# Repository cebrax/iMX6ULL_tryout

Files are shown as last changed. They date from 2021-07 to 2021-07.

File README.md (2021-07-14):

# iMX6ULL_tryout

This is a test board to get iMX6ULL up and running using KiCad 5.99

The board has:

- iMX6ULL 900MHz MCIMX6Y2DVM09AB
- 512MB DDR3L RAM
- An SD card slot
- 2 x USB connector
- An ethernet PHY and connector with magnetics
- A 40-pin LCD connector
- Various pinouts of GPIO, RS232 and such..

Front
Back


StressTest

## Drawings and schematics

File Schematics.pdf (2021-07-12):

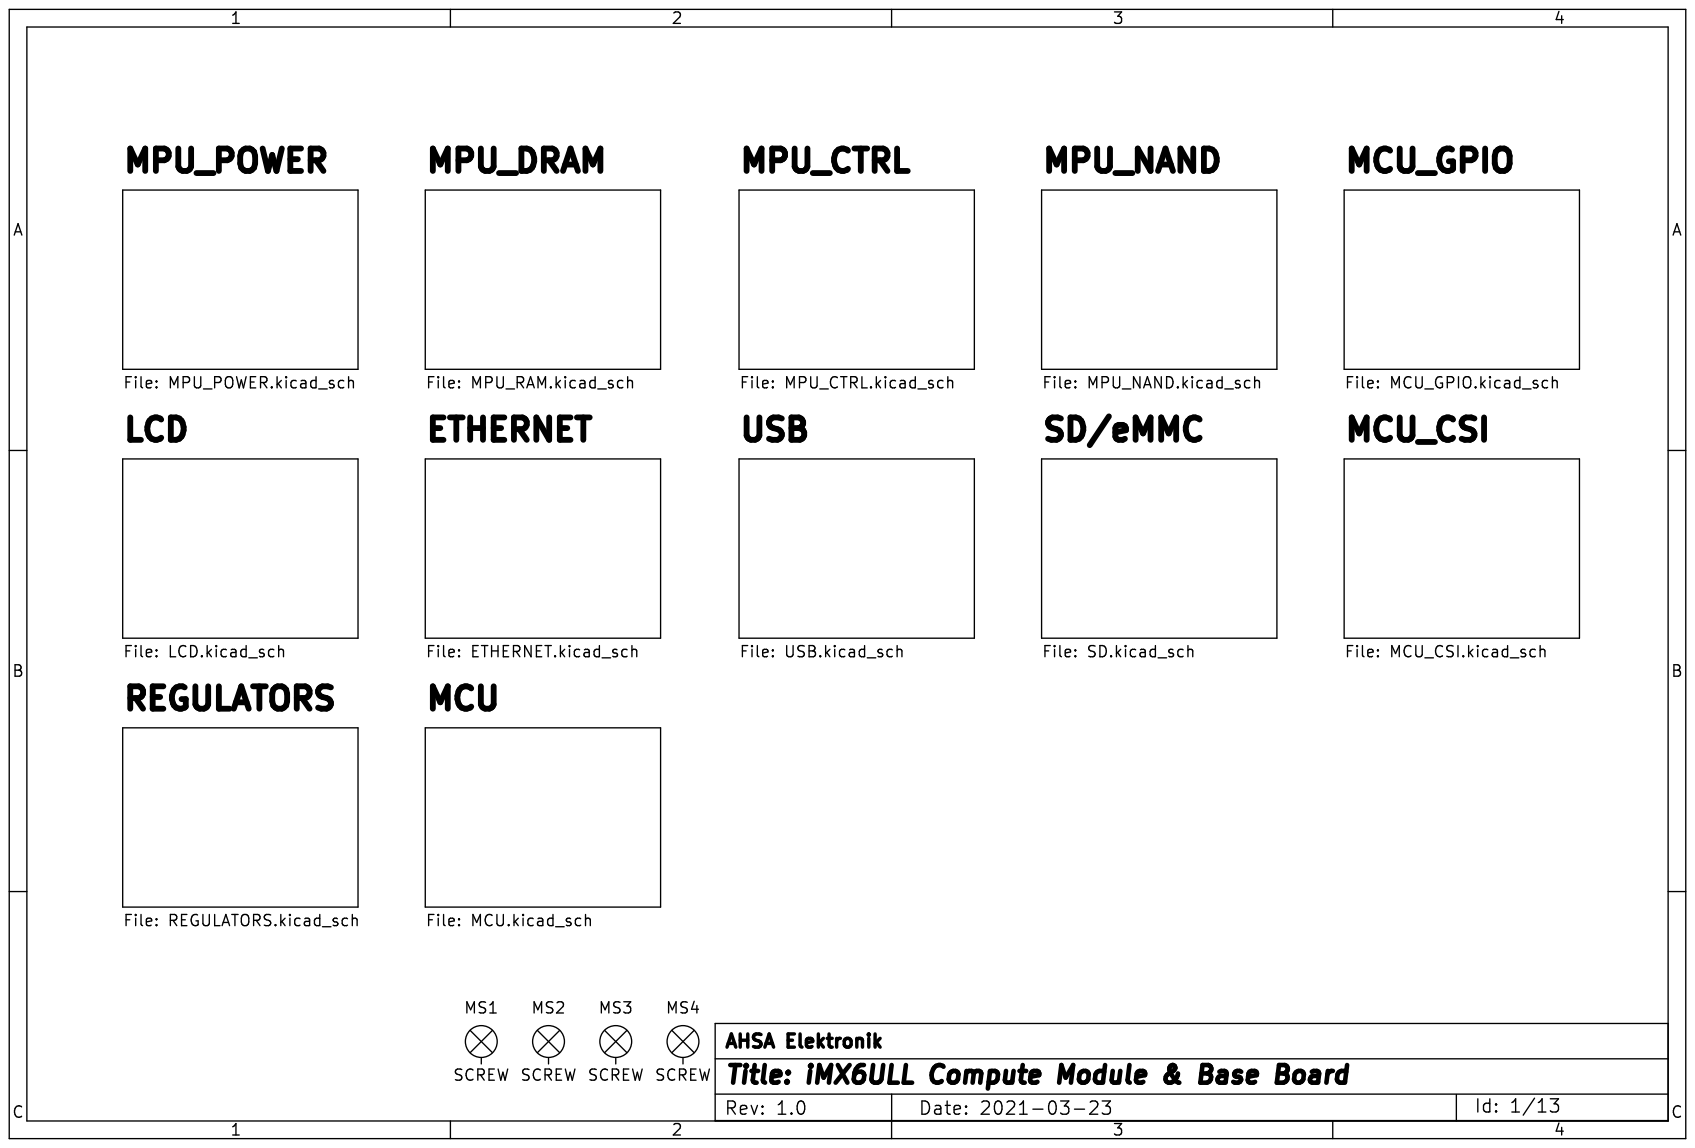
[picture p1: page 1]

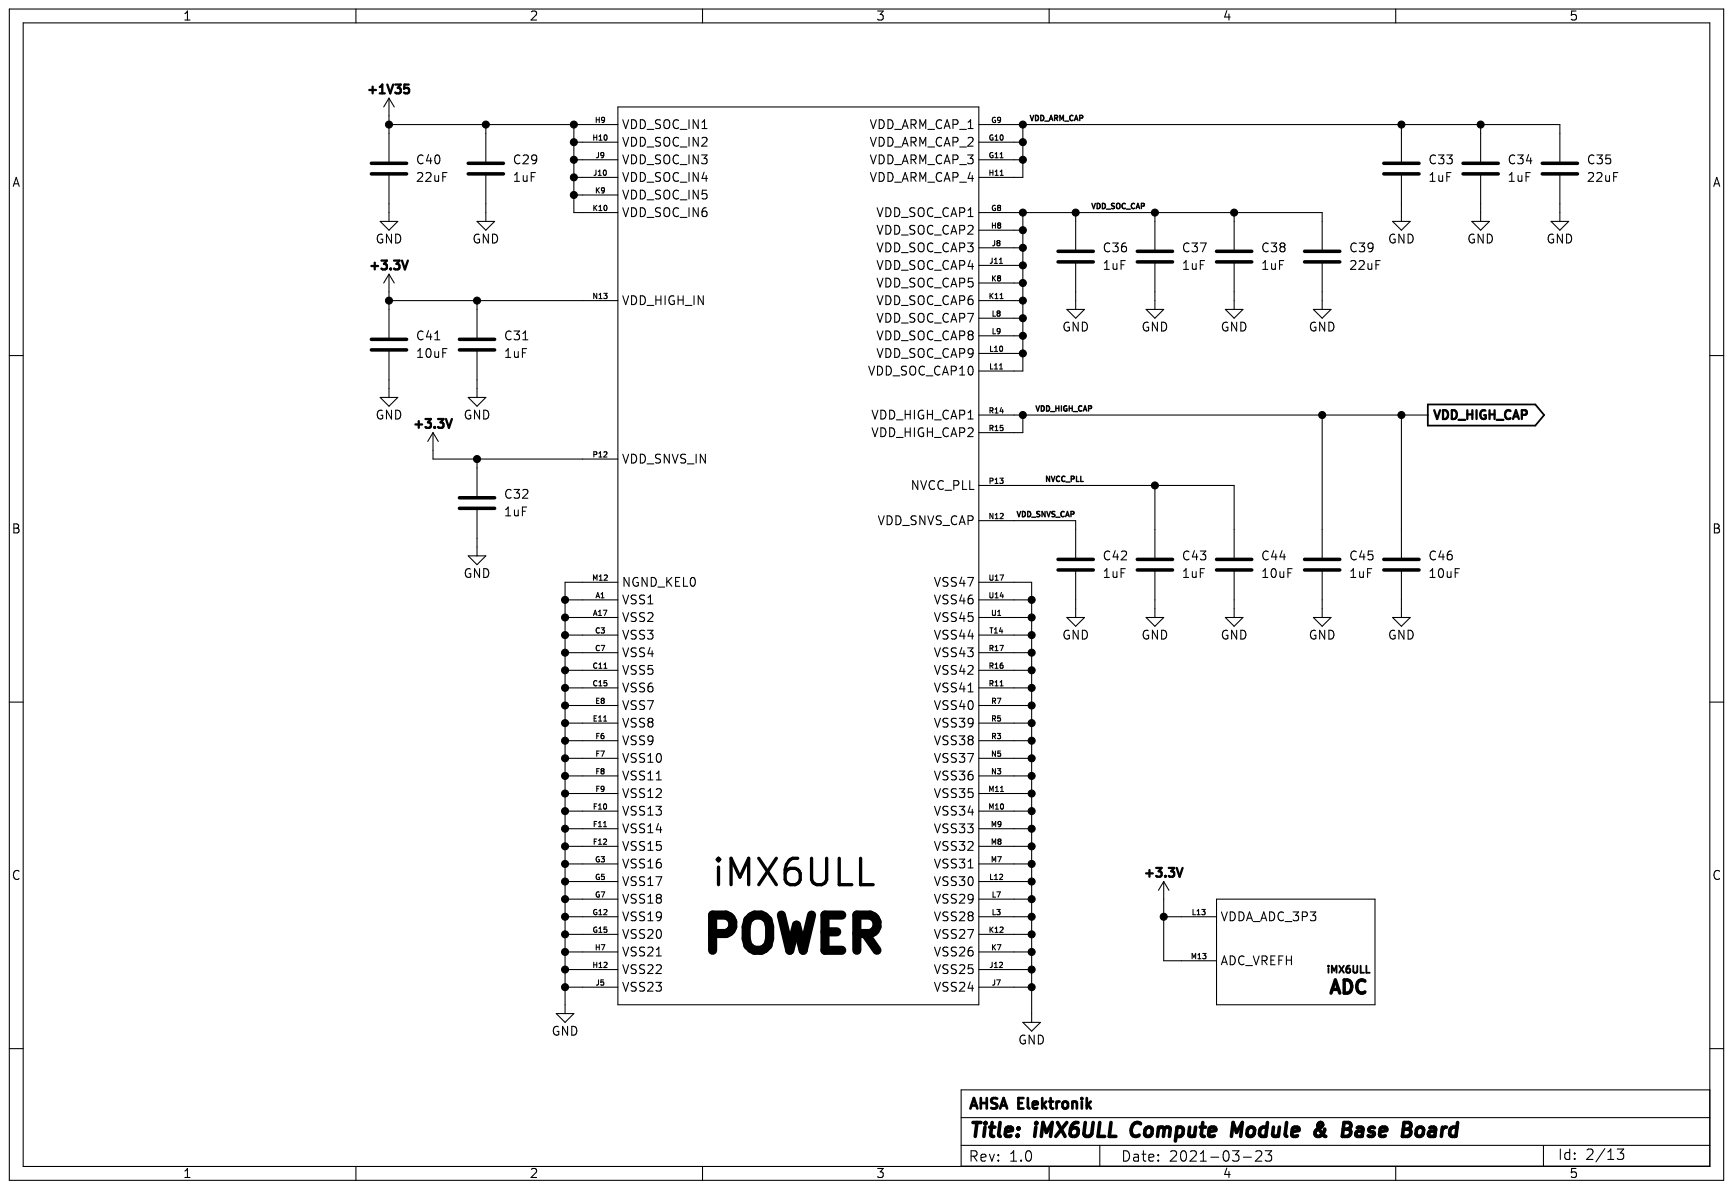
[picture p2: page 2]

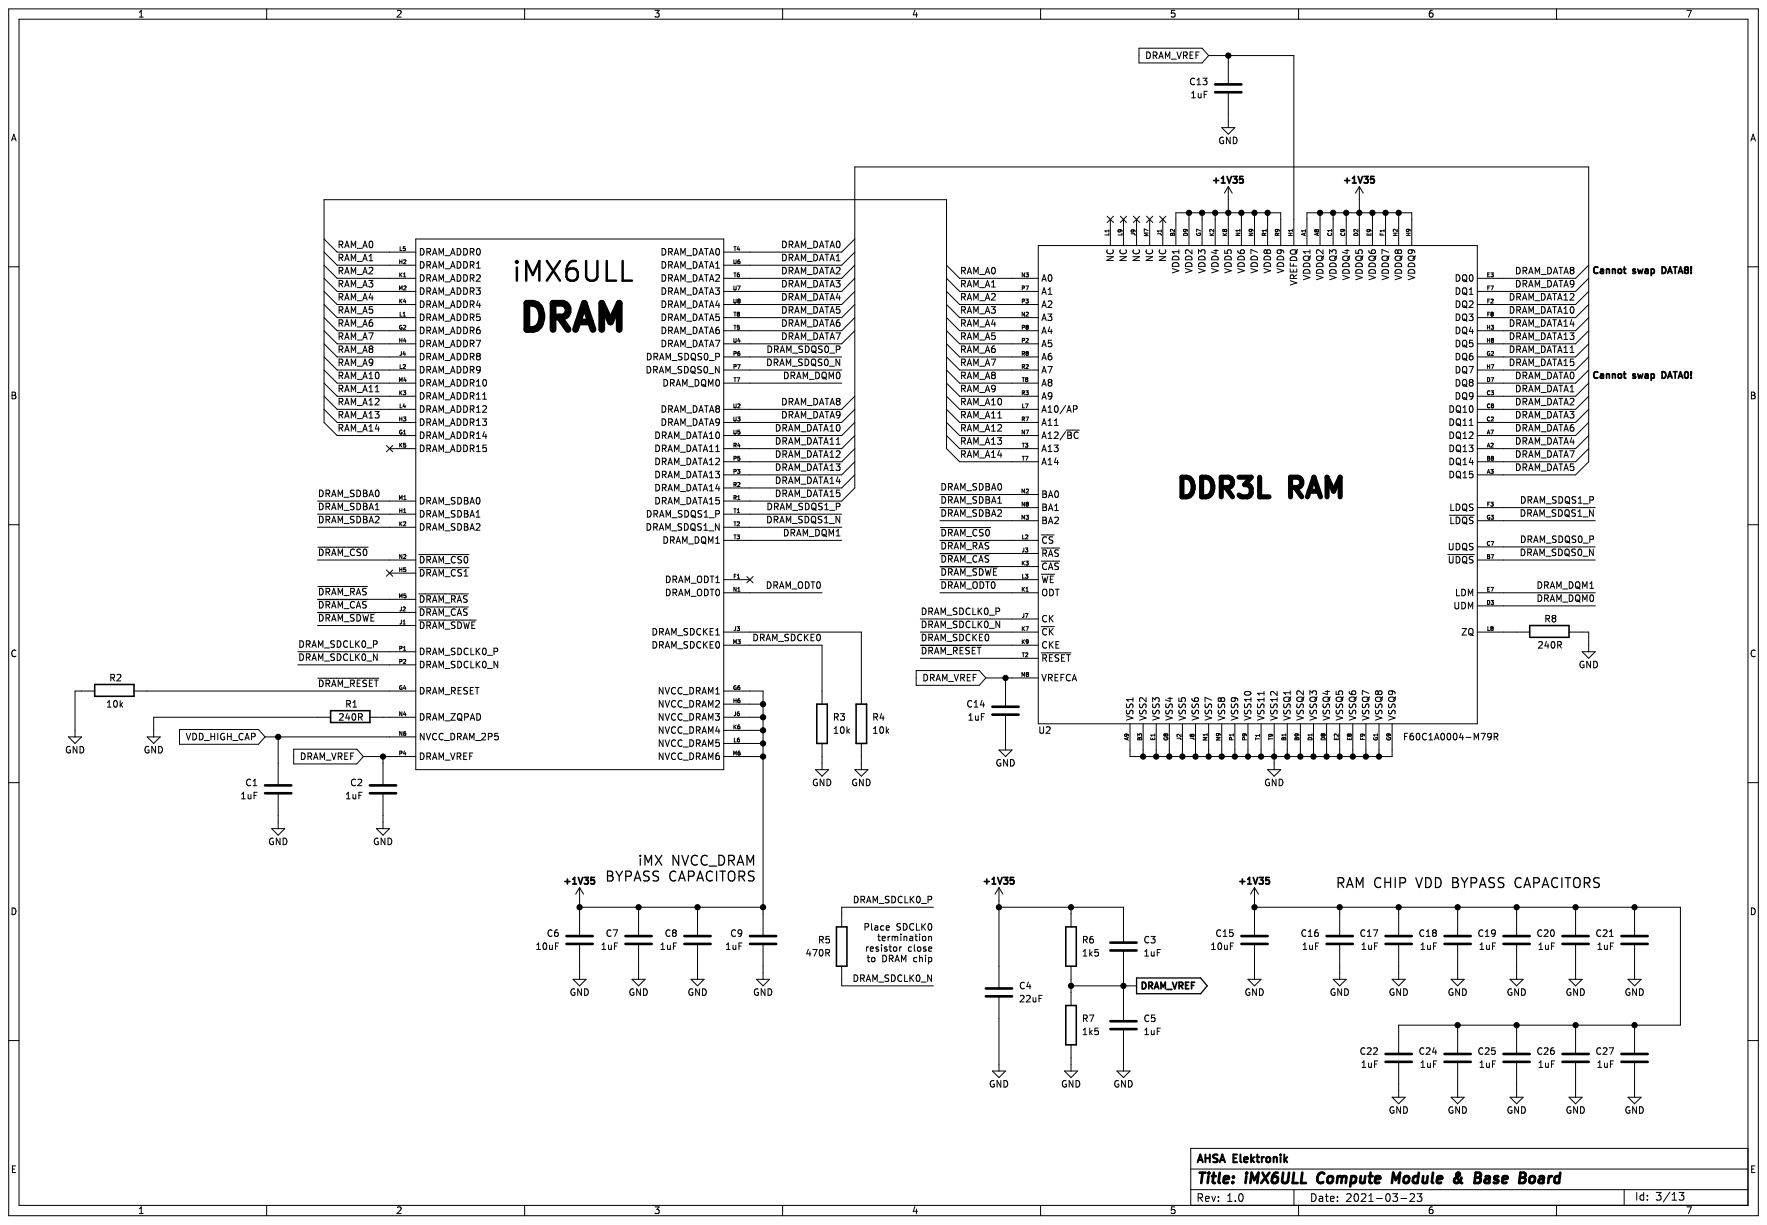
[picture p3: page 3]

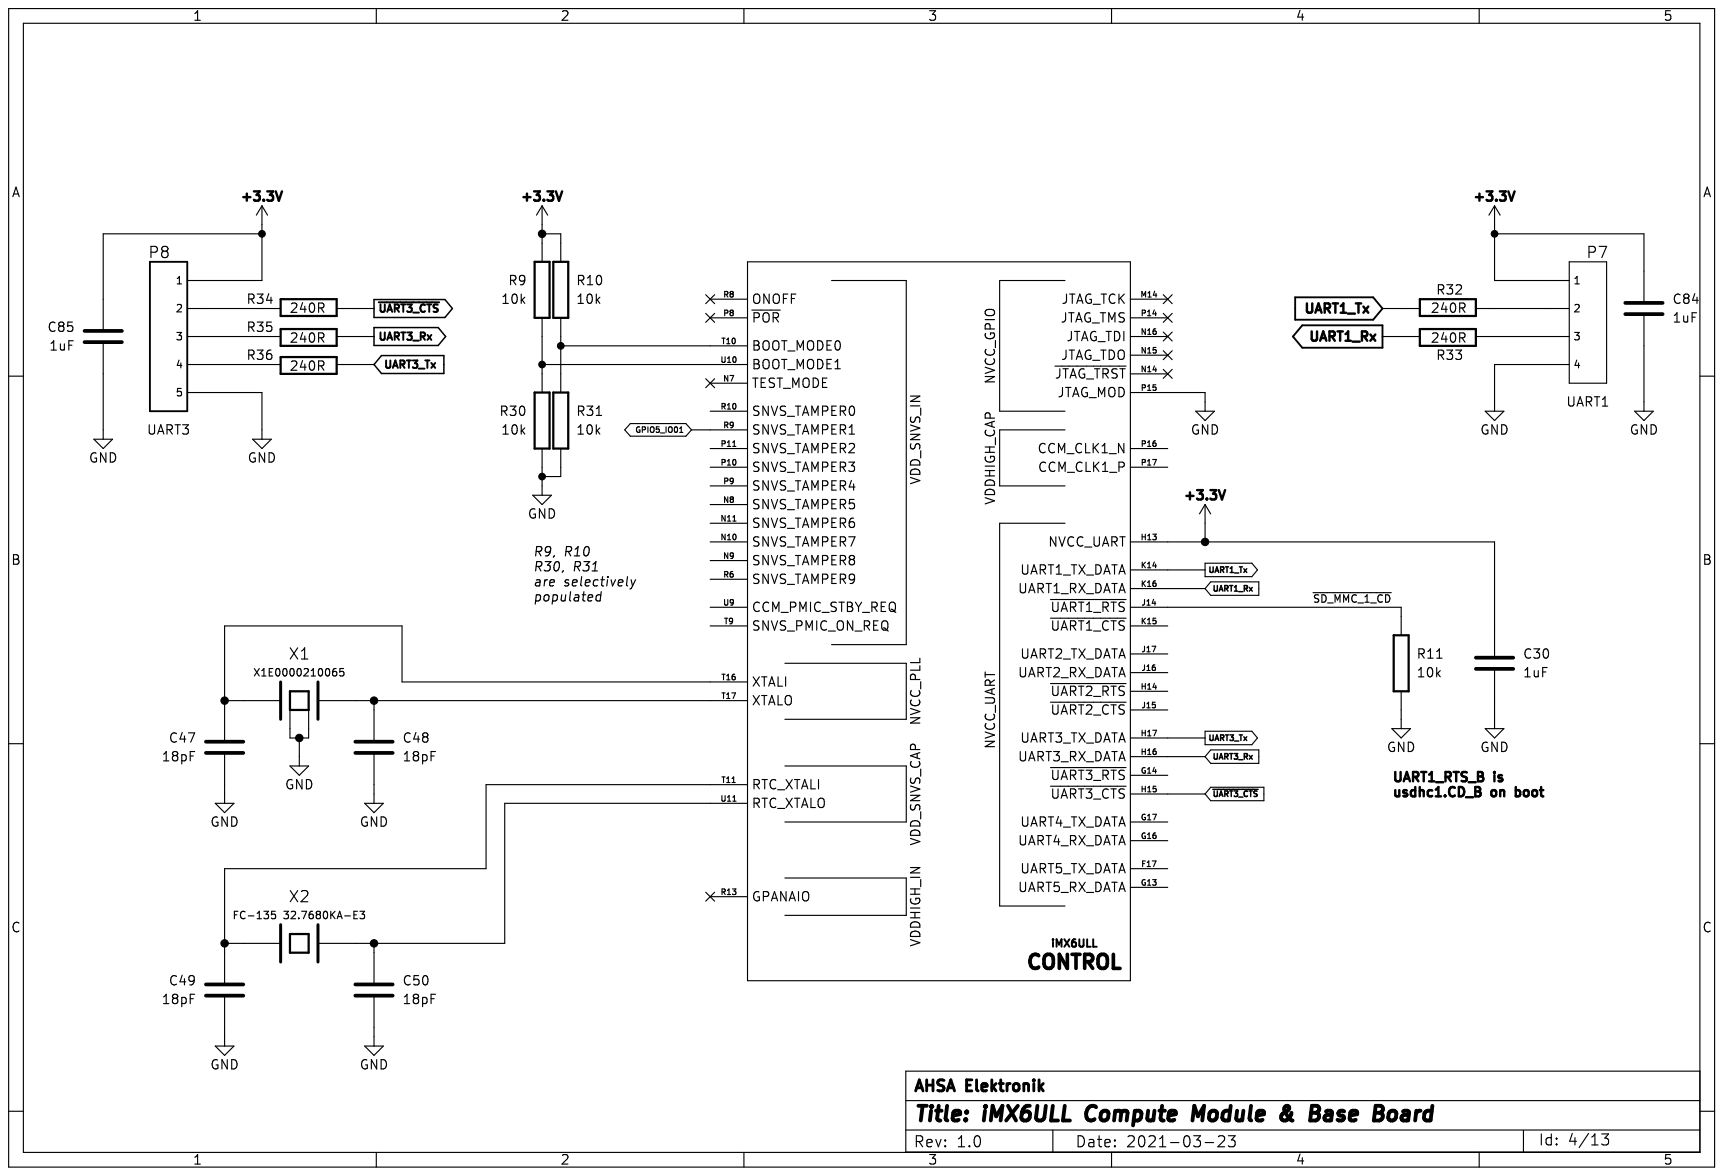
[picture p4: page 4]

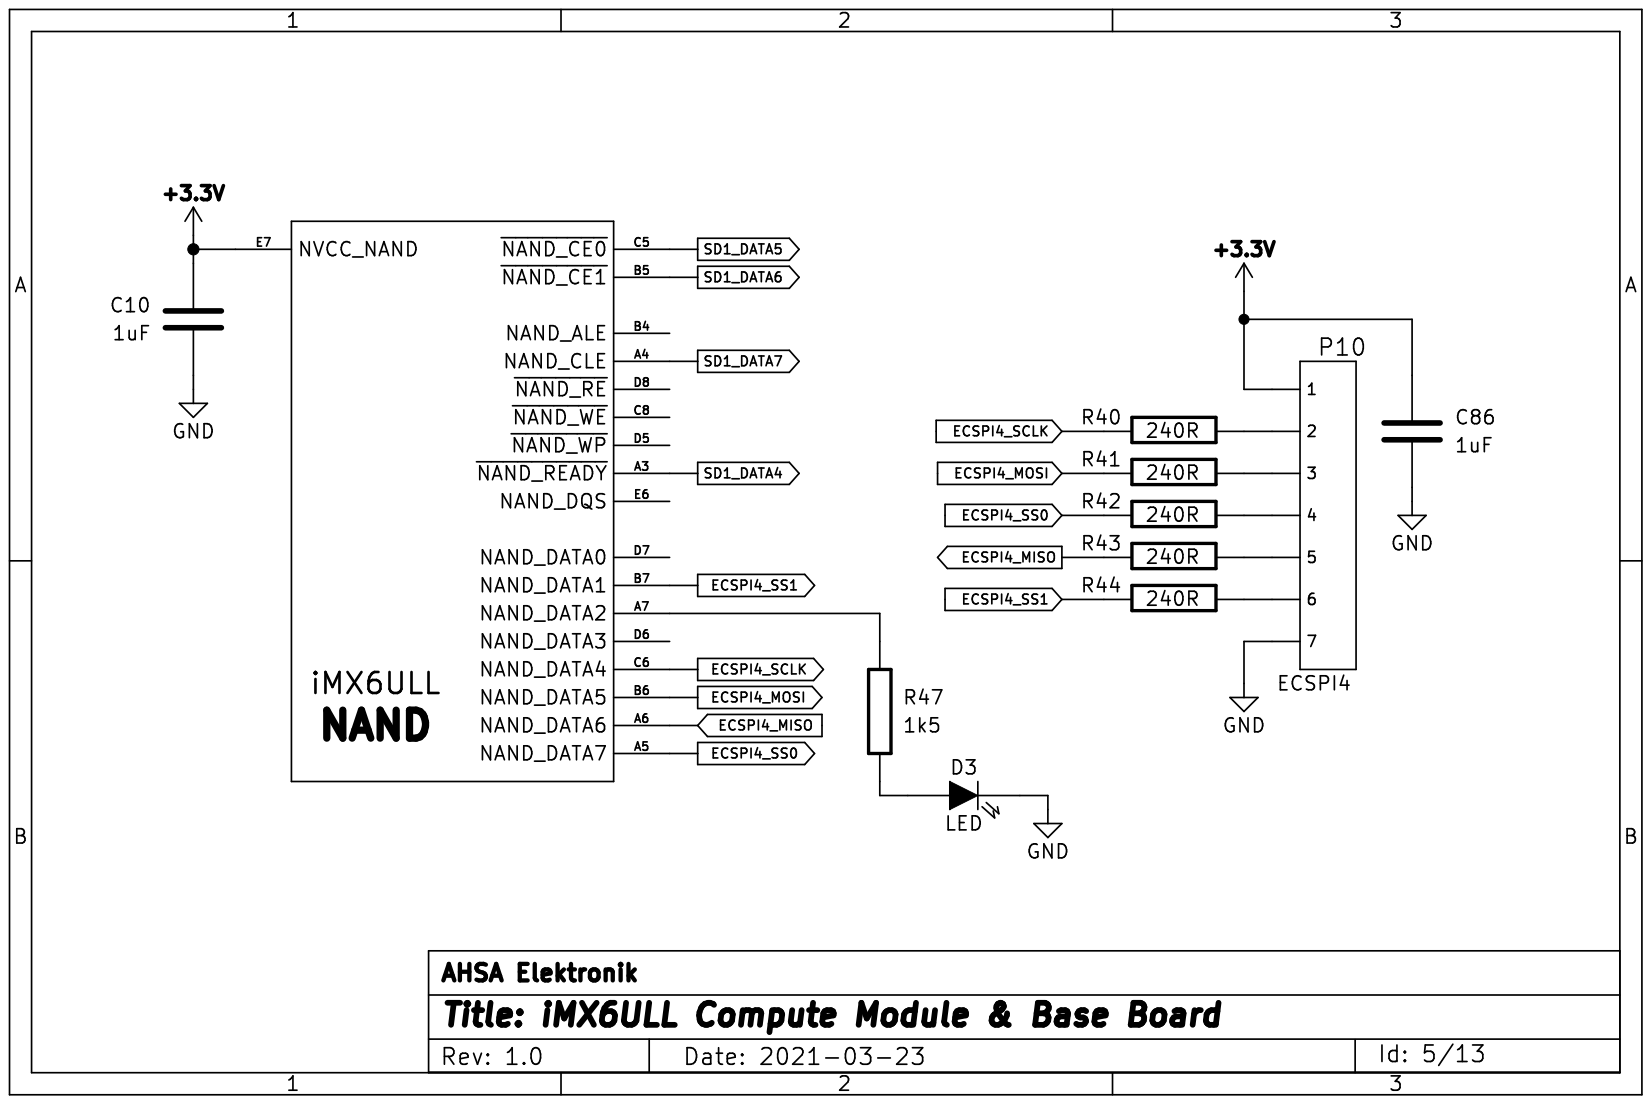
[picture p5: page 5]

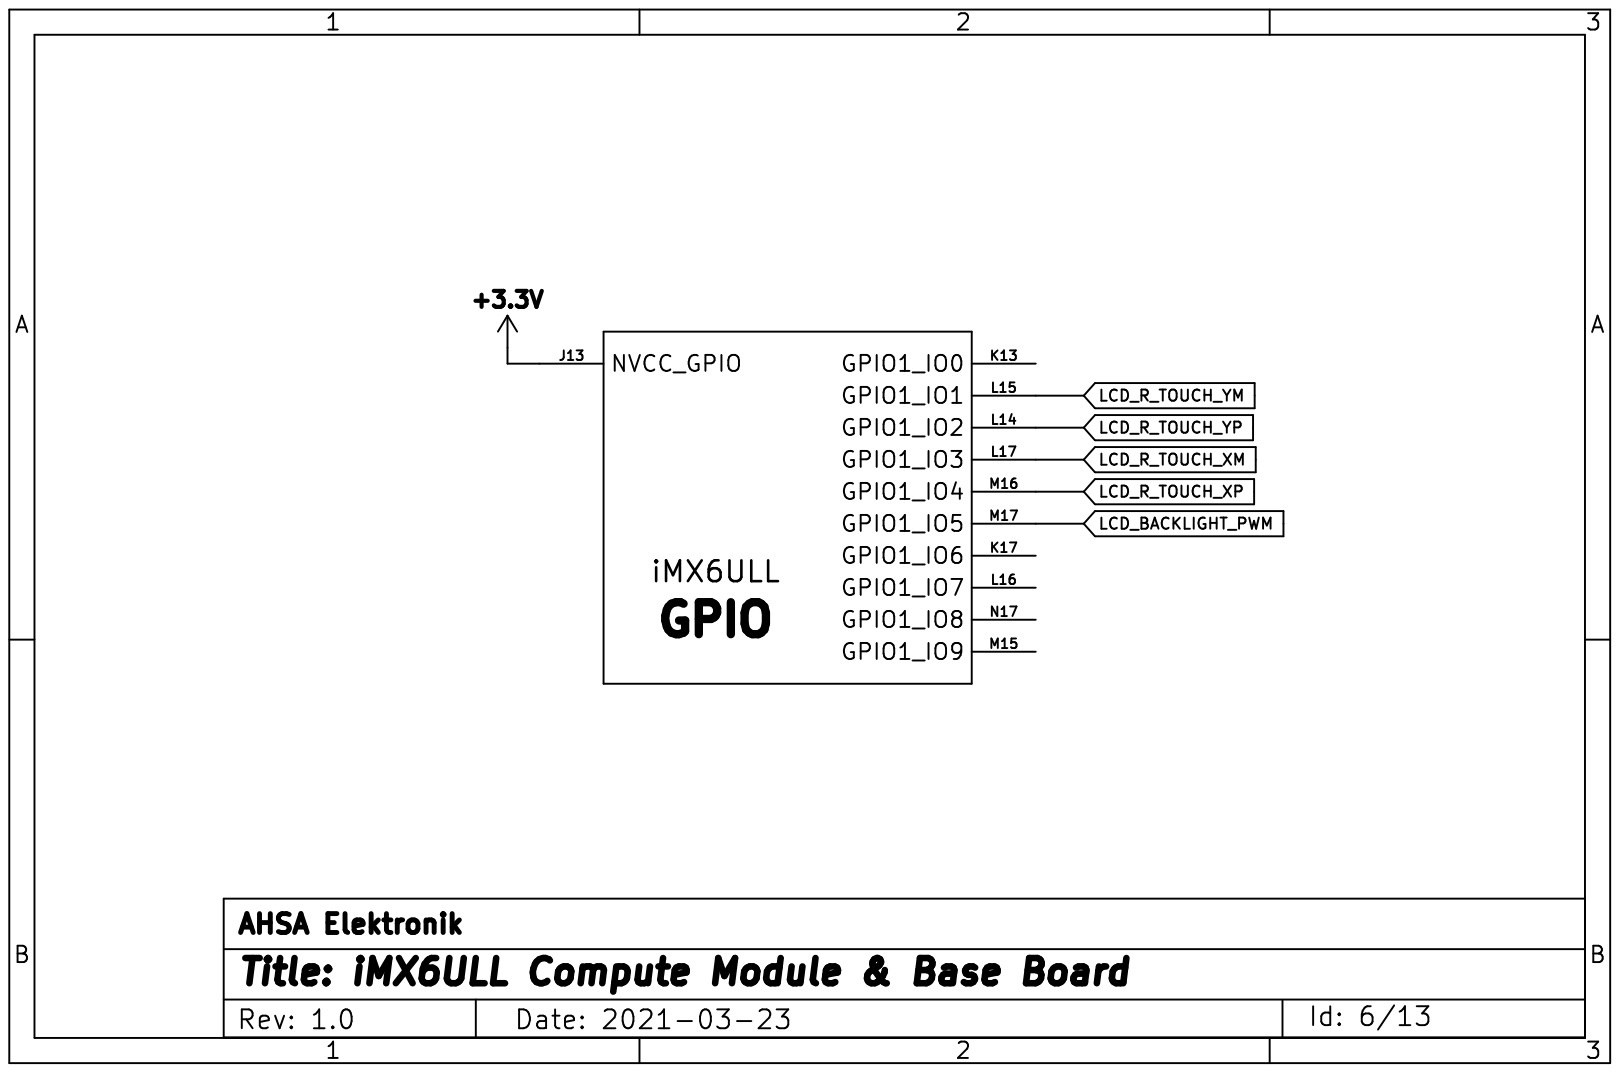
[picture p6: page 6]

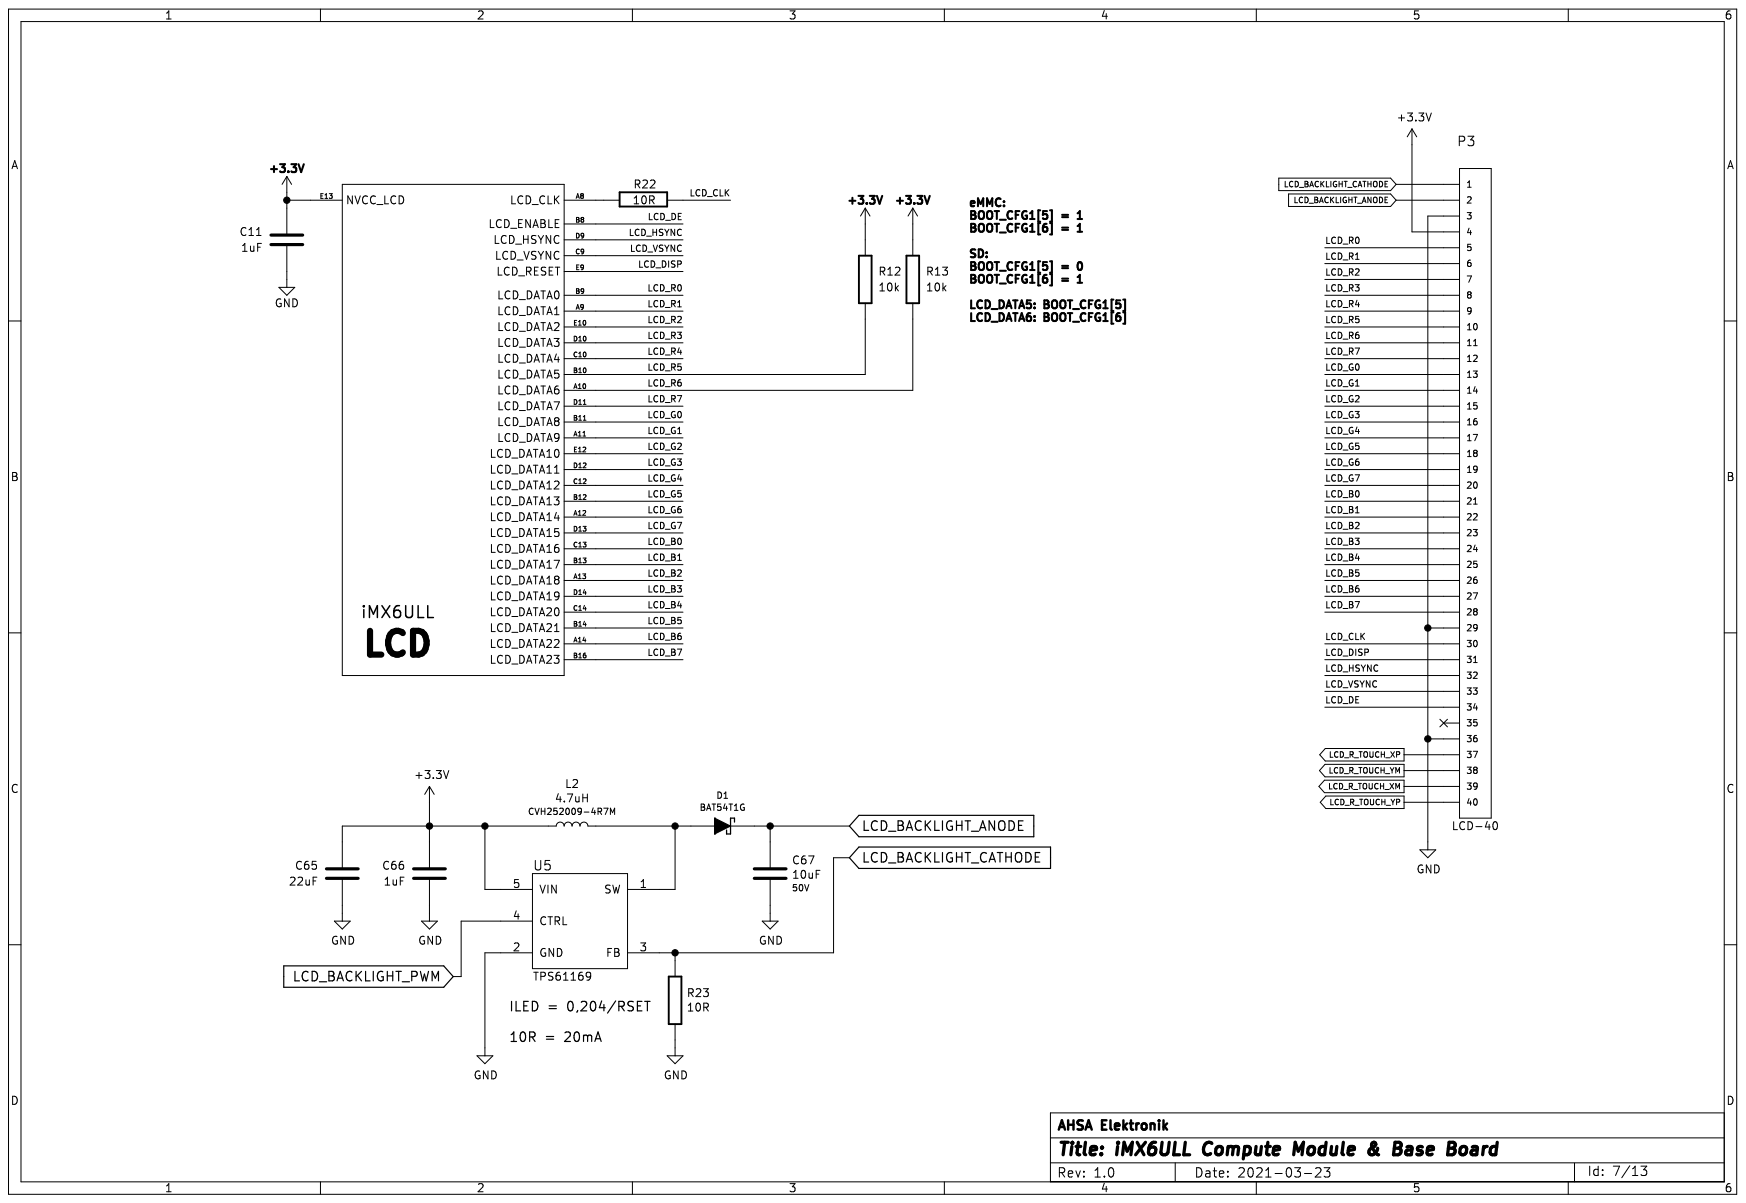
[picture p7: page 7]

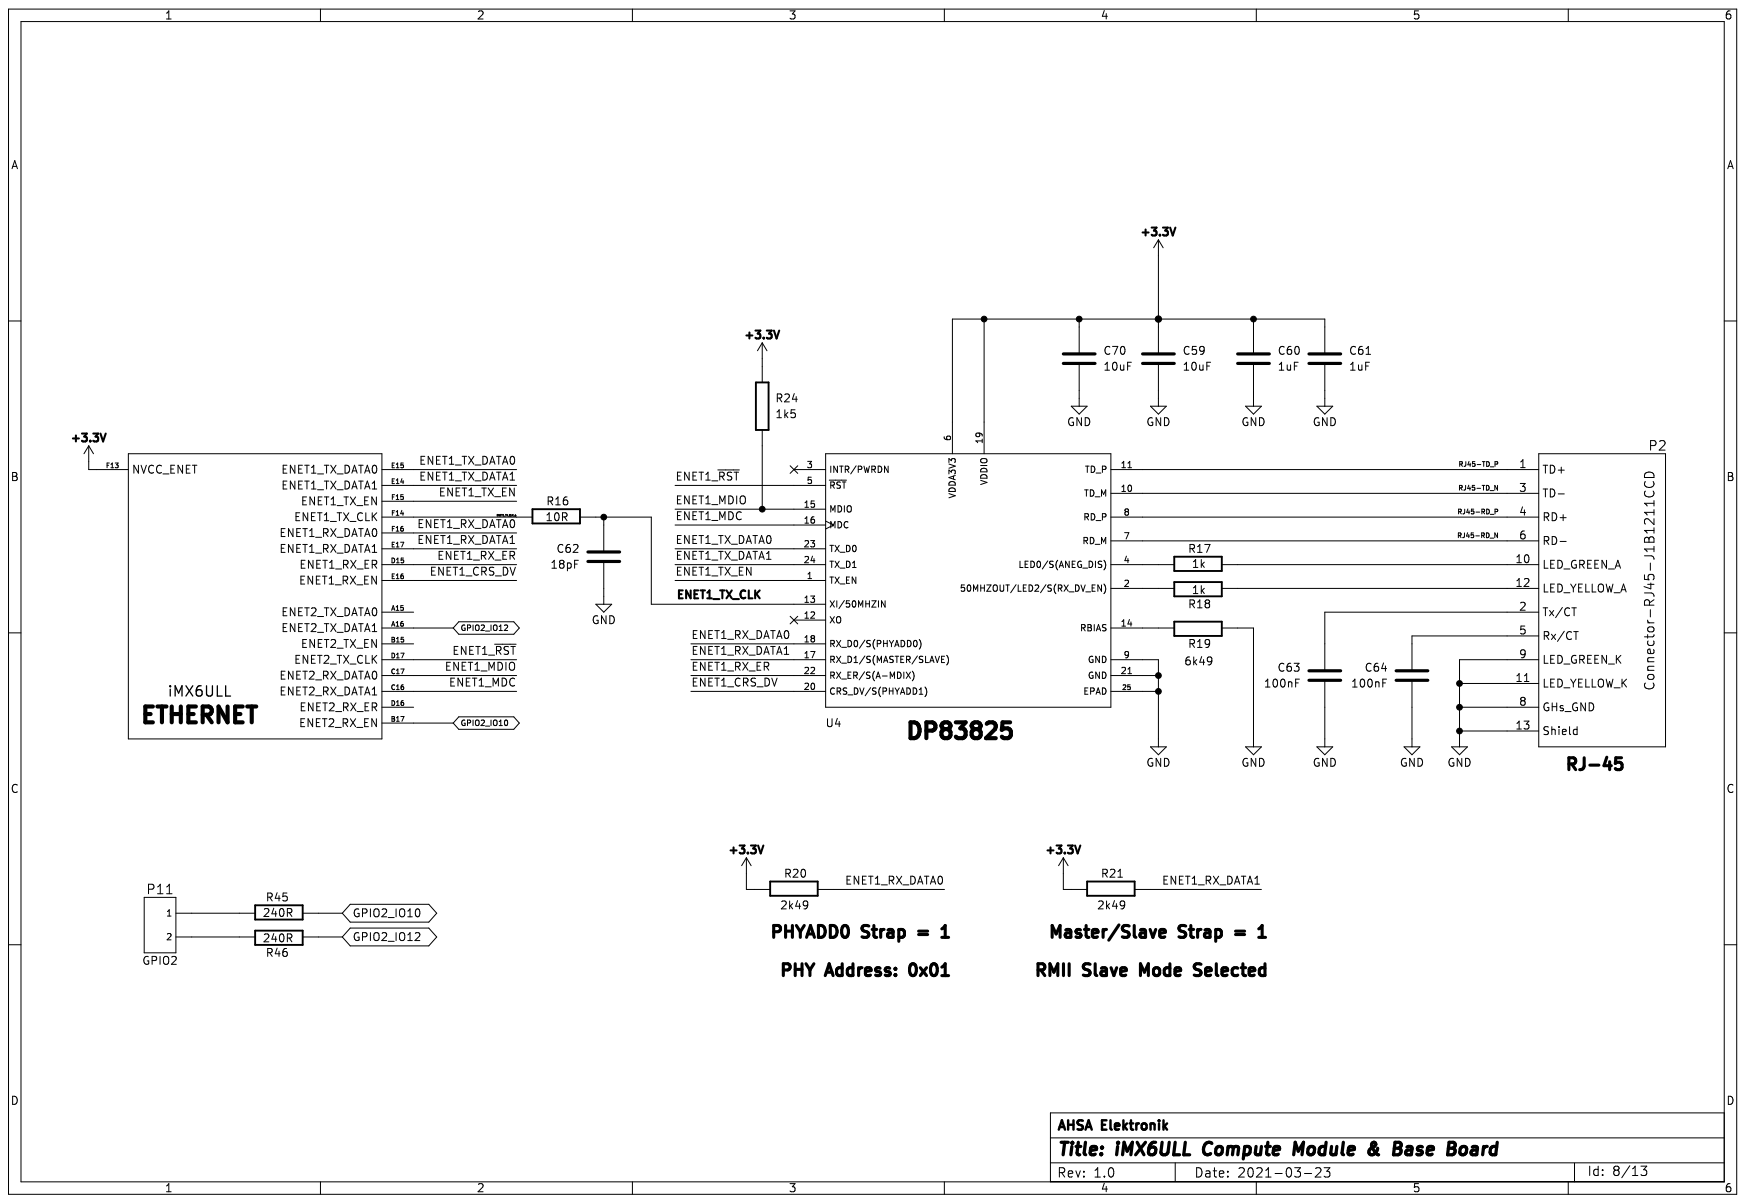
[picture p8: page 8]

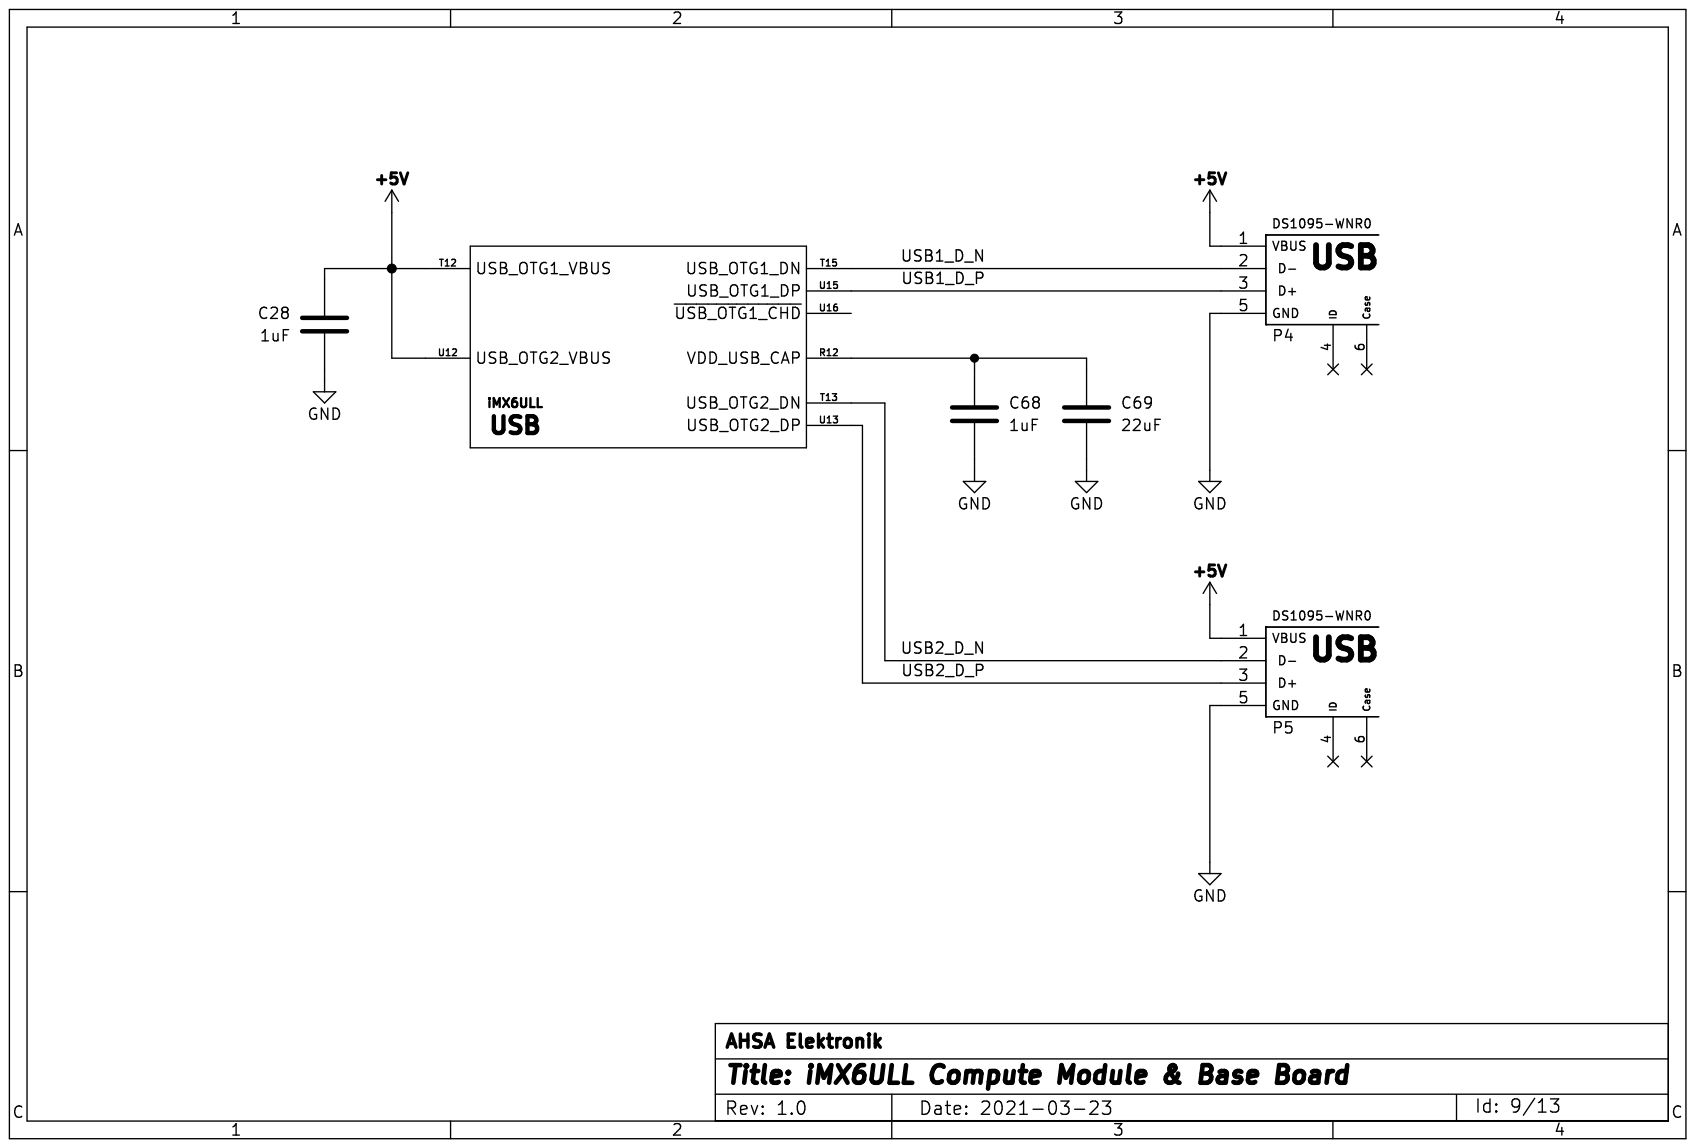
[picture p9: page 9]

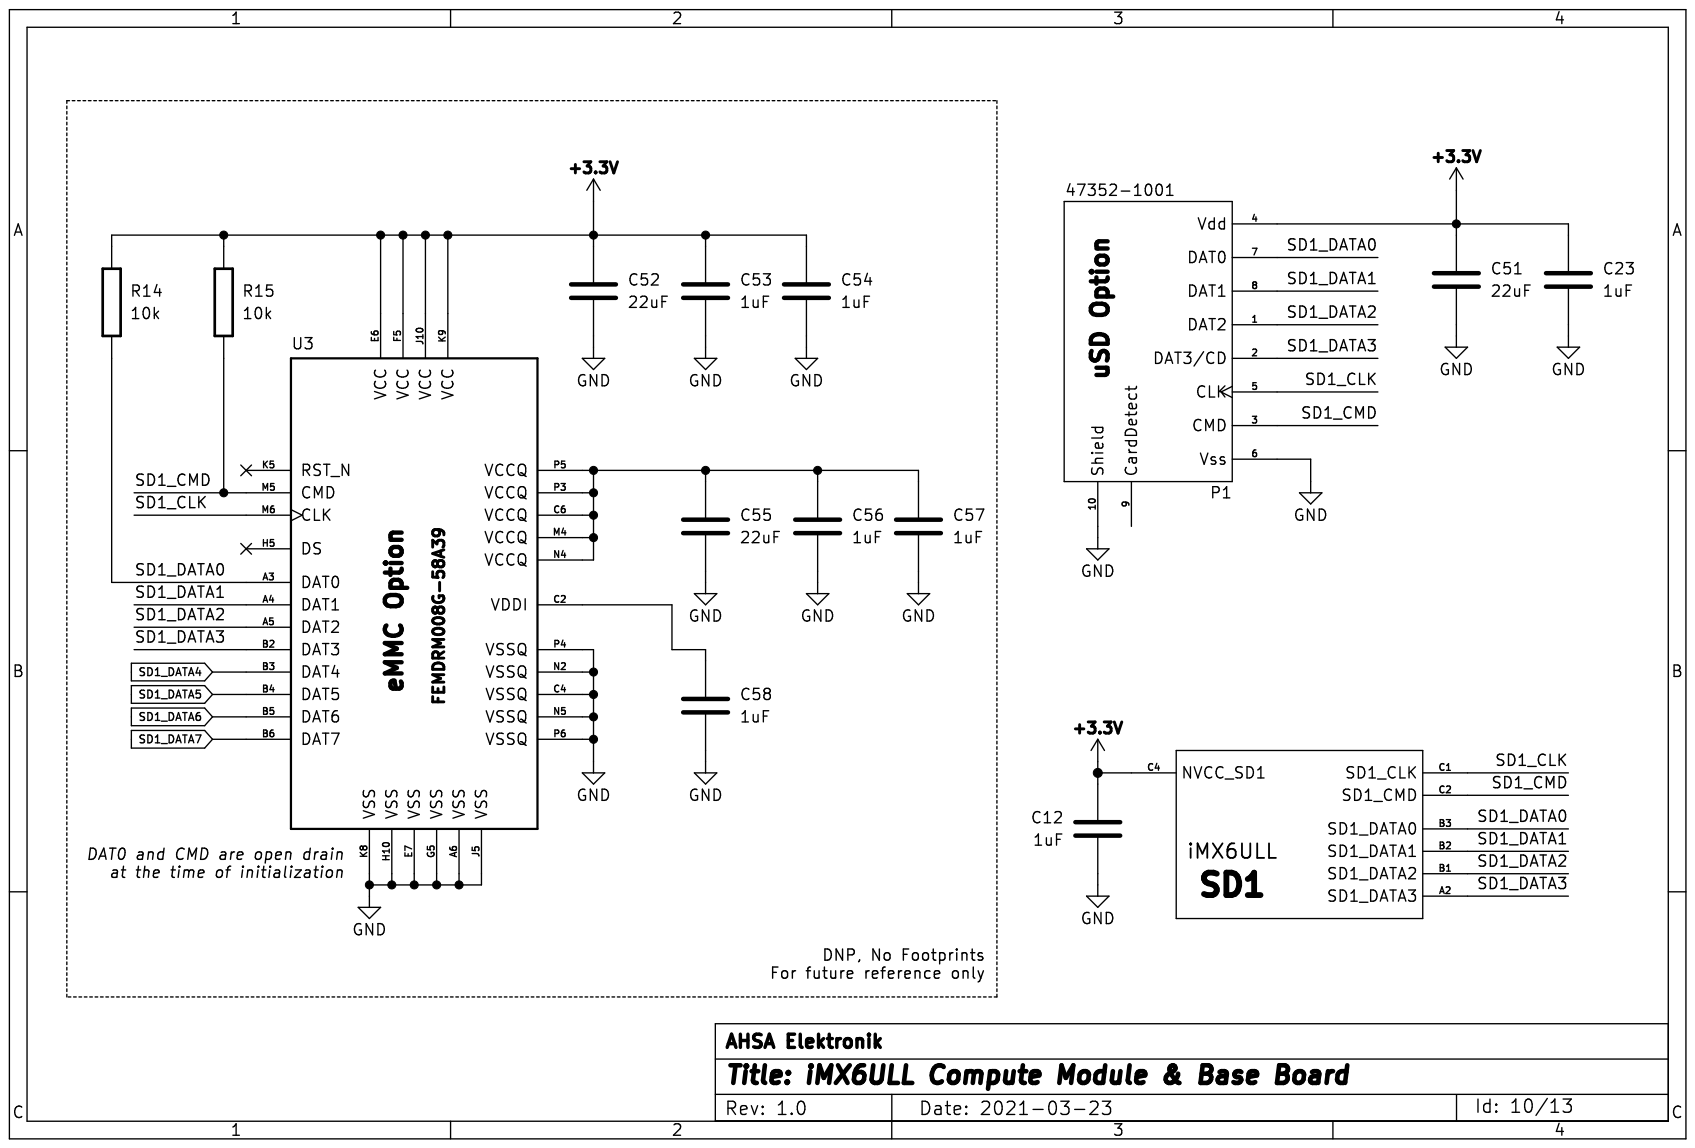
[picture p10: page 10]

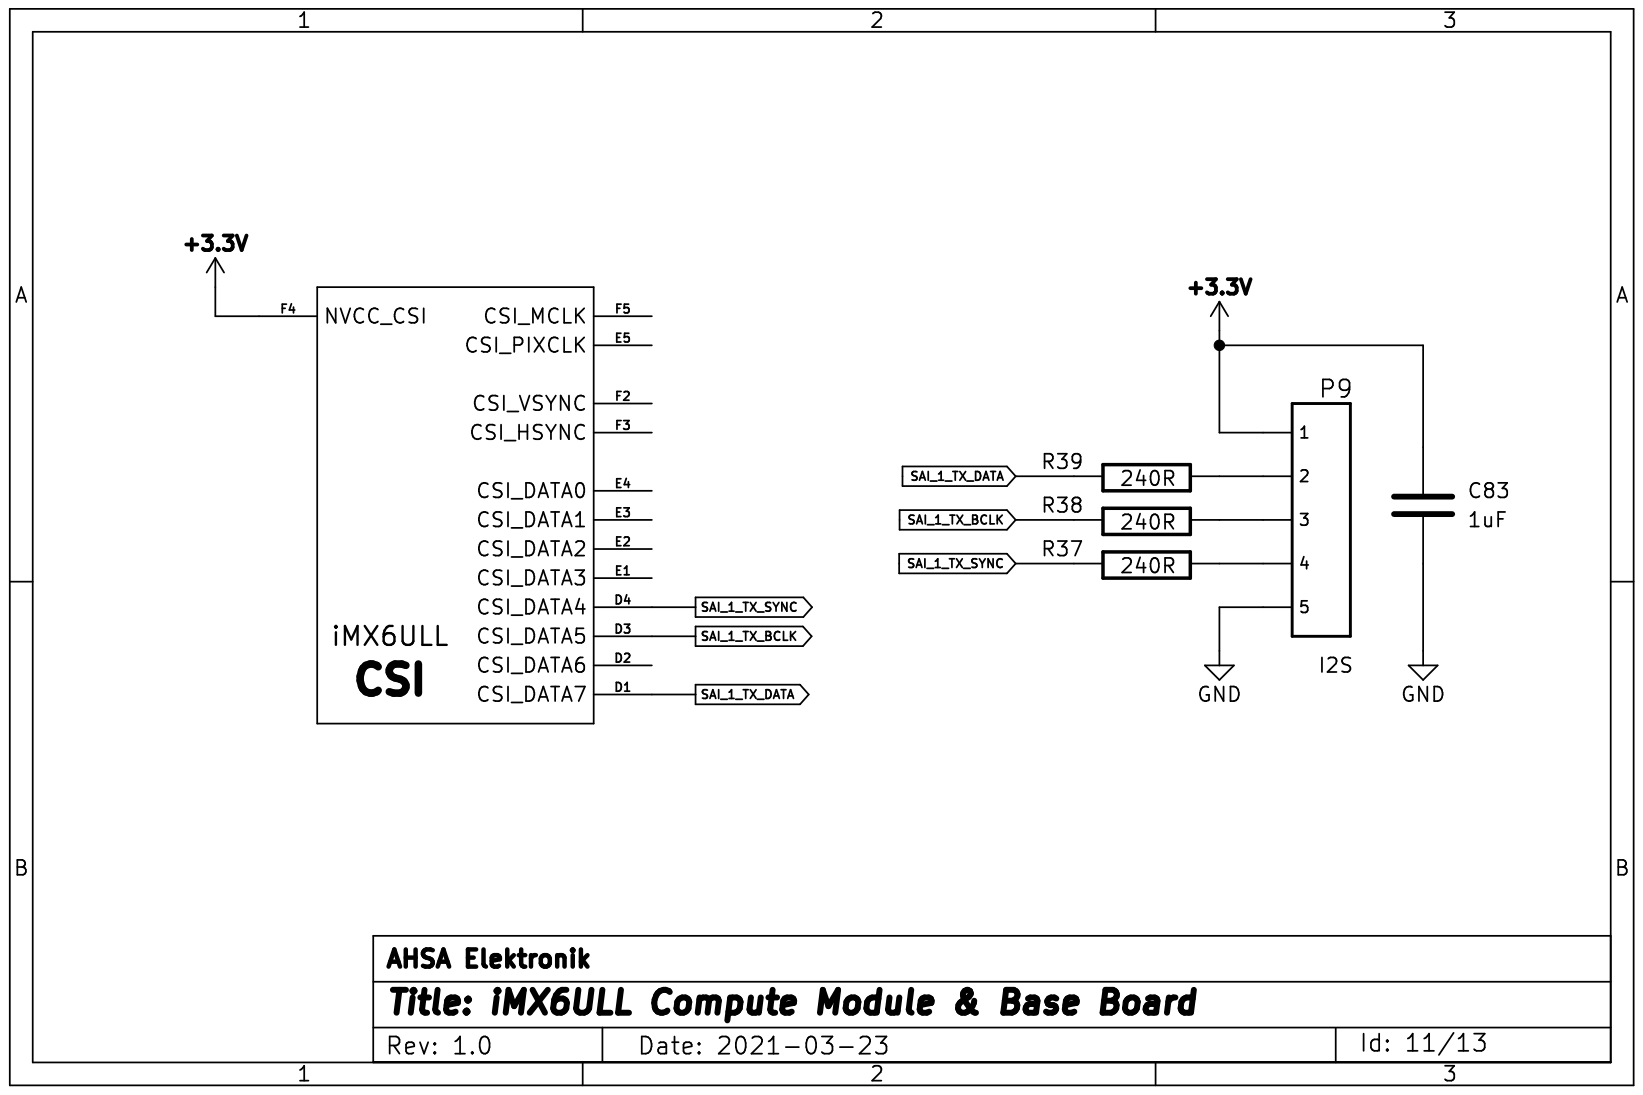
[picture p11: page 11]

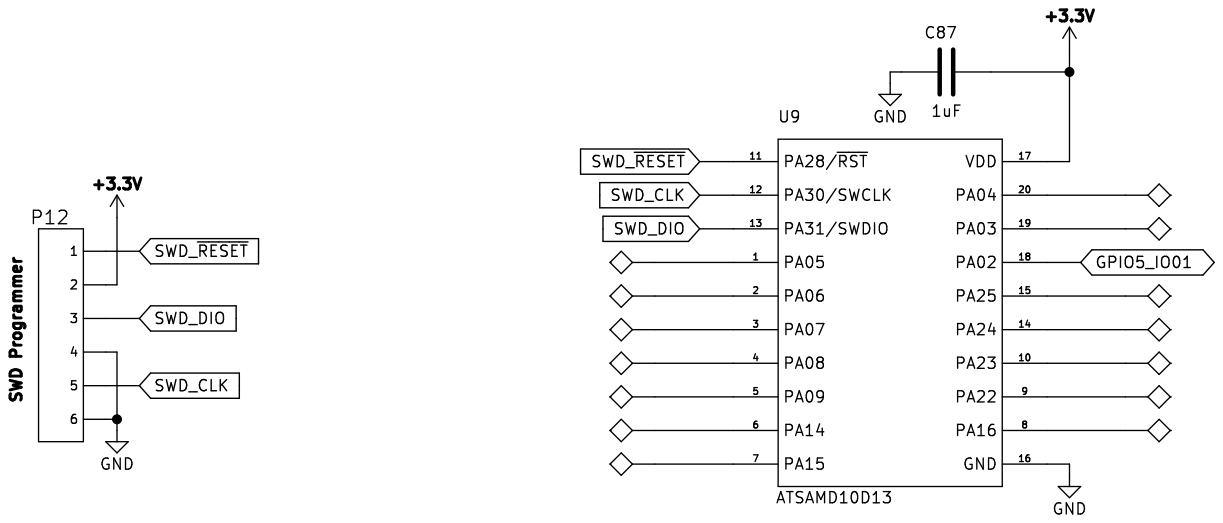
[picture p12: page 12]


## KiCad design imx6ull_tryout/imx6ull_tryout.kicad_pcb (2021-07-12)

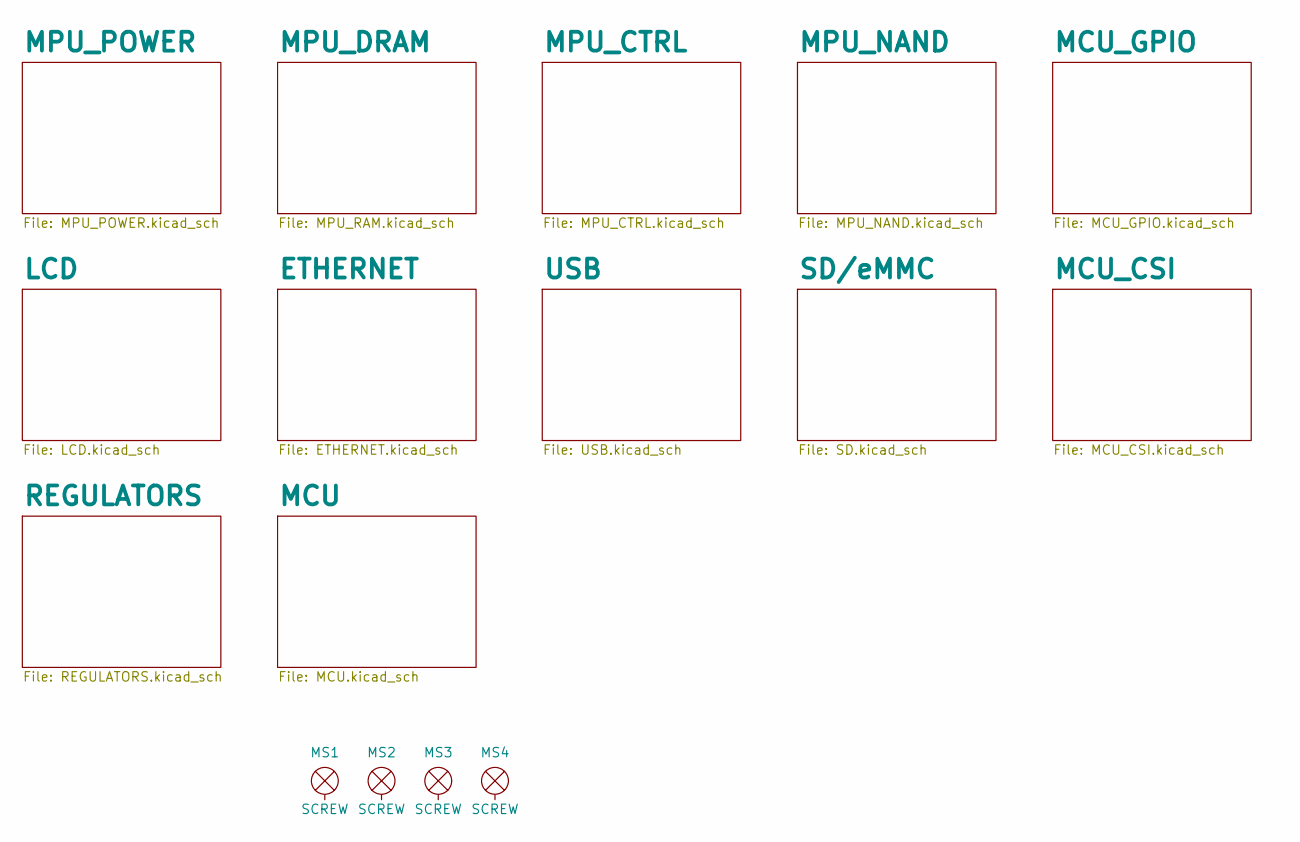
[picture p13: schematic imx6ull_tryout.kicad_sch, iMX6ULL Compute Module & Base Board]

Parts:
MS1, MS2, MS3, MS4: SCREW; M3-Screw-Front

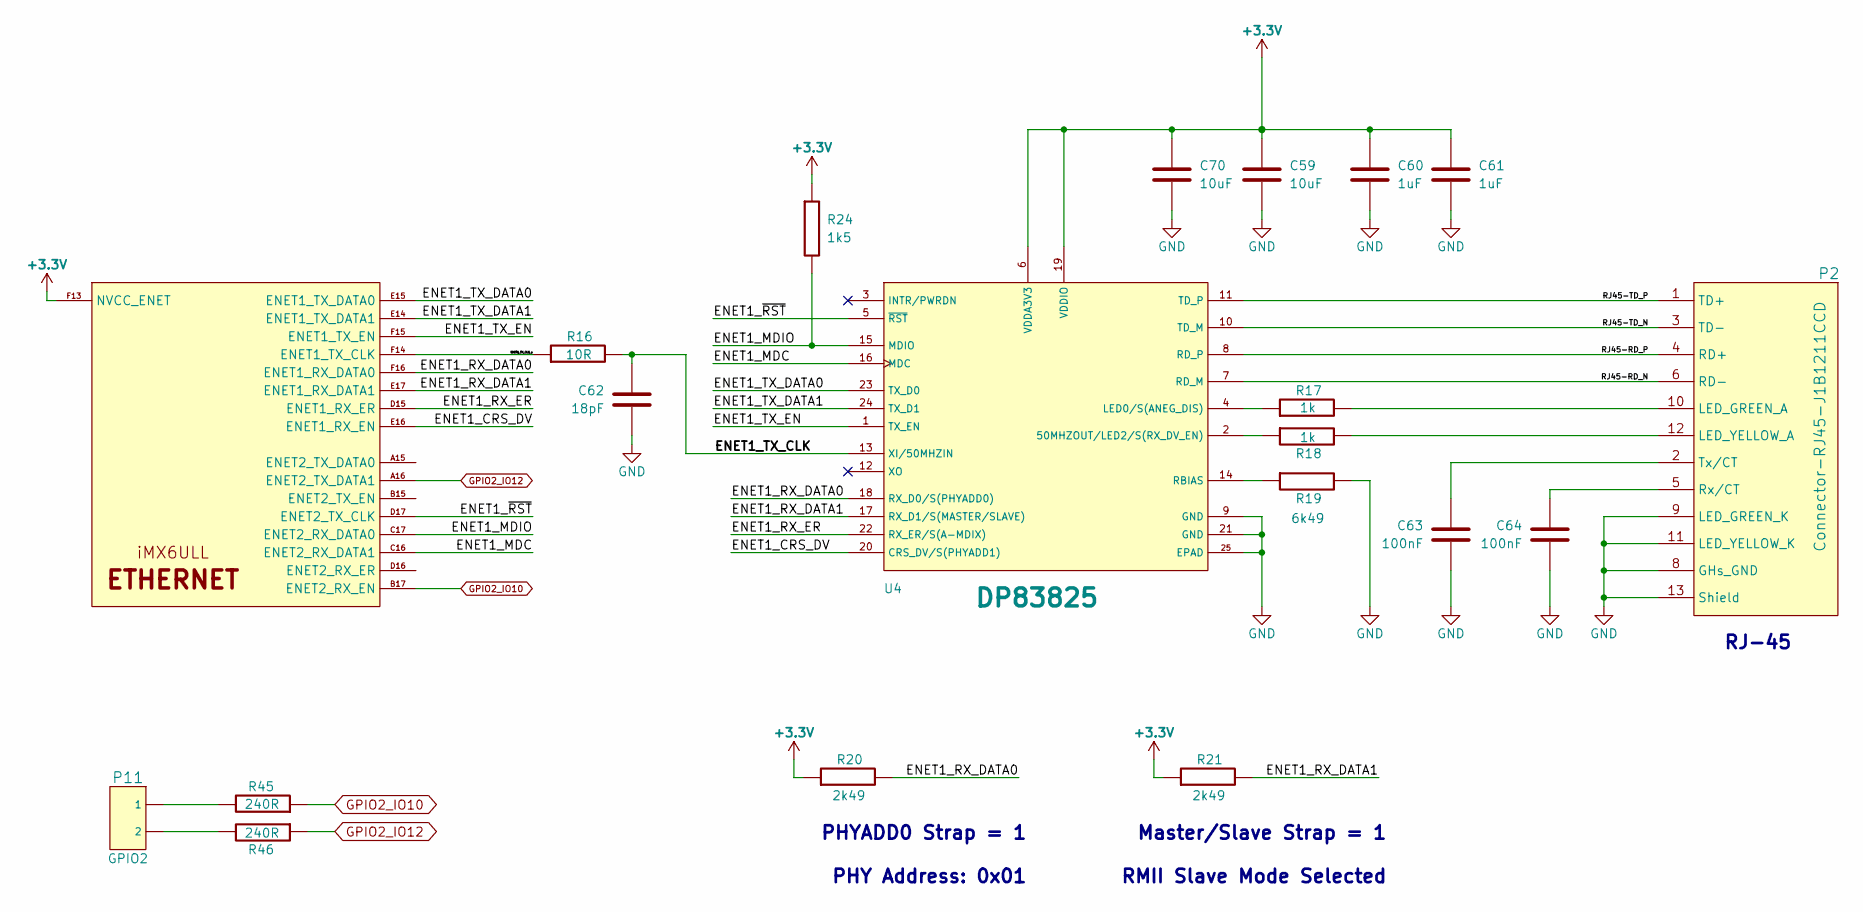
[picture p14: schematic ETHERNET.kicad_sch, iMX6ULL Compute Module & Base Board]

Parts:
C59, C70: 10uF; IPC-SMD-C-0402; Voltage 16V
C60, C61: 1uF; IPC-SMD-C-0402; Voltage 10V
C62: 18pF; IPC-SMD-C-0402; Voltage 50V
C63, C64: 100nF; IPC-SMD-C-0805; Voltage 50V
P2: Connector-RJ45-J1B1211CCD
P11: GPIO2; Connector-Male-Breakaway-2pins
R16: 10R; IPC-SMD-R-0402
R17, R18: 1k; IPC-SMD-R-0805
R19: 6k49; IPC-SMD-R-0603
R20, R21: 2k49; IPC-SMD-R-0603
R24: 1k5; IPC-SMD-R-0603
R45, R46: 240R; IPC-SMD-R-0402
U1: iMX6ULL; BGA289C80P17X17_1400X1400X132N
U4: DP83825; IPC-WQFN-24

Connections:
+3V3: C59.1, C60.1, C61.1, C70.1, R20.1, R21.1, R24.1, U1.F13 (NVCC_ENET), U4.6 (VDDA3V3), U4.19 (VDDIO); also elsewhere on the board
/ETHERNET/ENET1_CRS_DV: U1.E16 (ENET1_RX_EN), U4.20 (CRS_DV/S(PHYADD1))
/ETHERNET/ENET1_MDC: U1.C16 (ENET2_RX_DATA1), U4.16 (MDC)
/ETHERNET/ENET1_MDIO: R24.2, U1.C17 (ENET2_RX_DATA0), U4.15 (MDIO)
/ETHERNET/ENET1_RX_DATA0: R20.2, U1.F16 (ENET1_RX_DATA0), U4.18 (RX_D0/S(PHYADD0))
/ETHERNET/ENET1_RX_DATA1: R21.2, U1.E17 (ENET1_RX_DATA1), U4.17 (RX_D1/S(MASTER/SLAVE))
/ETHERNET/ENET1_RX_ER: U1.D15 (ENET1_RX_ER), U4.22 (RX_ER/S(A-MDIX))
/ETHERNET/ENET1_TX_CLK: C62.1, R16.2, U4.13 (XI/50MHZIN)
/ETHERNET/ENET1_TX_CLK_s: R16.1, U1.F14 (ENET1_TX_CLK)
/ETHERNET/ENET1_TX_DATA0: U1.E15 (ENET1_TX_DATA0), U4.23 (TX_D0)
/ETHERNET/ENET1_TX_DATA1: U1.E14 (ENET1_TX_DATA1), U4.24 (TX_D1)
/ETHERNET/ENET1_TX_EN: U1.F15 (ENET1_TX_EN), U4.1 (TX_EN)
/ETHERNET/ENET1_~RST: U1.D17 (ENET2_TX_CLK), U4.5 (~RST)
/ETHERNET/RJ45-RD_N: P2.6 (RD-), U4.7 (RD_M)
/ETHERNET/RJ45-RD_P: P2.4 (RD+), U4.8 (RD_P)
/ETHERNET/RJ45-TD_N: P2.3 (TD-), U4.10 (TD_M)
/ETHERNET/RJ45-TD_P: P2.1 (TD+), U4.11 (TD_P)
GND: C59.2, C60.2, C61.2, C62.2, C63.2, C64.2, C70.2, P2.8 (GHs_GND), P2.9 (LED_GREEN_K), P2.11 (LED_YELLOW_K), P2.13 (Shield), R19.2, U4.9 (GND), U4.21 (GND), U4.25 (EPAD); also elsewhere on the board
GPIO2_IO10: R45.1, U1.B17 (ENET2_RX_EN)
GPIO2_IO12: R46.1, U1.A16 (ENET2_TX_DATA1)
unnamed: C63.1, P2.2 (Tx/CT)
unnamed: C64.1, P2.5 (Rx/CT)
unnamed: P2.10 (LED_GREEN_A), R17.2
unnamed: P2.12 (LED_YELLOW_A), R18.2
unnamed: P11.1, R45.2
unnamed: P11.2, R46.2
unnamed: R17.1, U4.4 (LED0/S(ANEG_DIS))
unnamed: R18.1, U4.2 (50MHZOUT/LED2/S(RX_DV_EN))
unnamed: R19.1, U4.14 (RBIAS)

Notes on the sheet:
PHYADD0 Strap = 1 PHY Address: 0x01
Master/Slave Strap = 1 RMII Slave Mode Selected
RJ-45

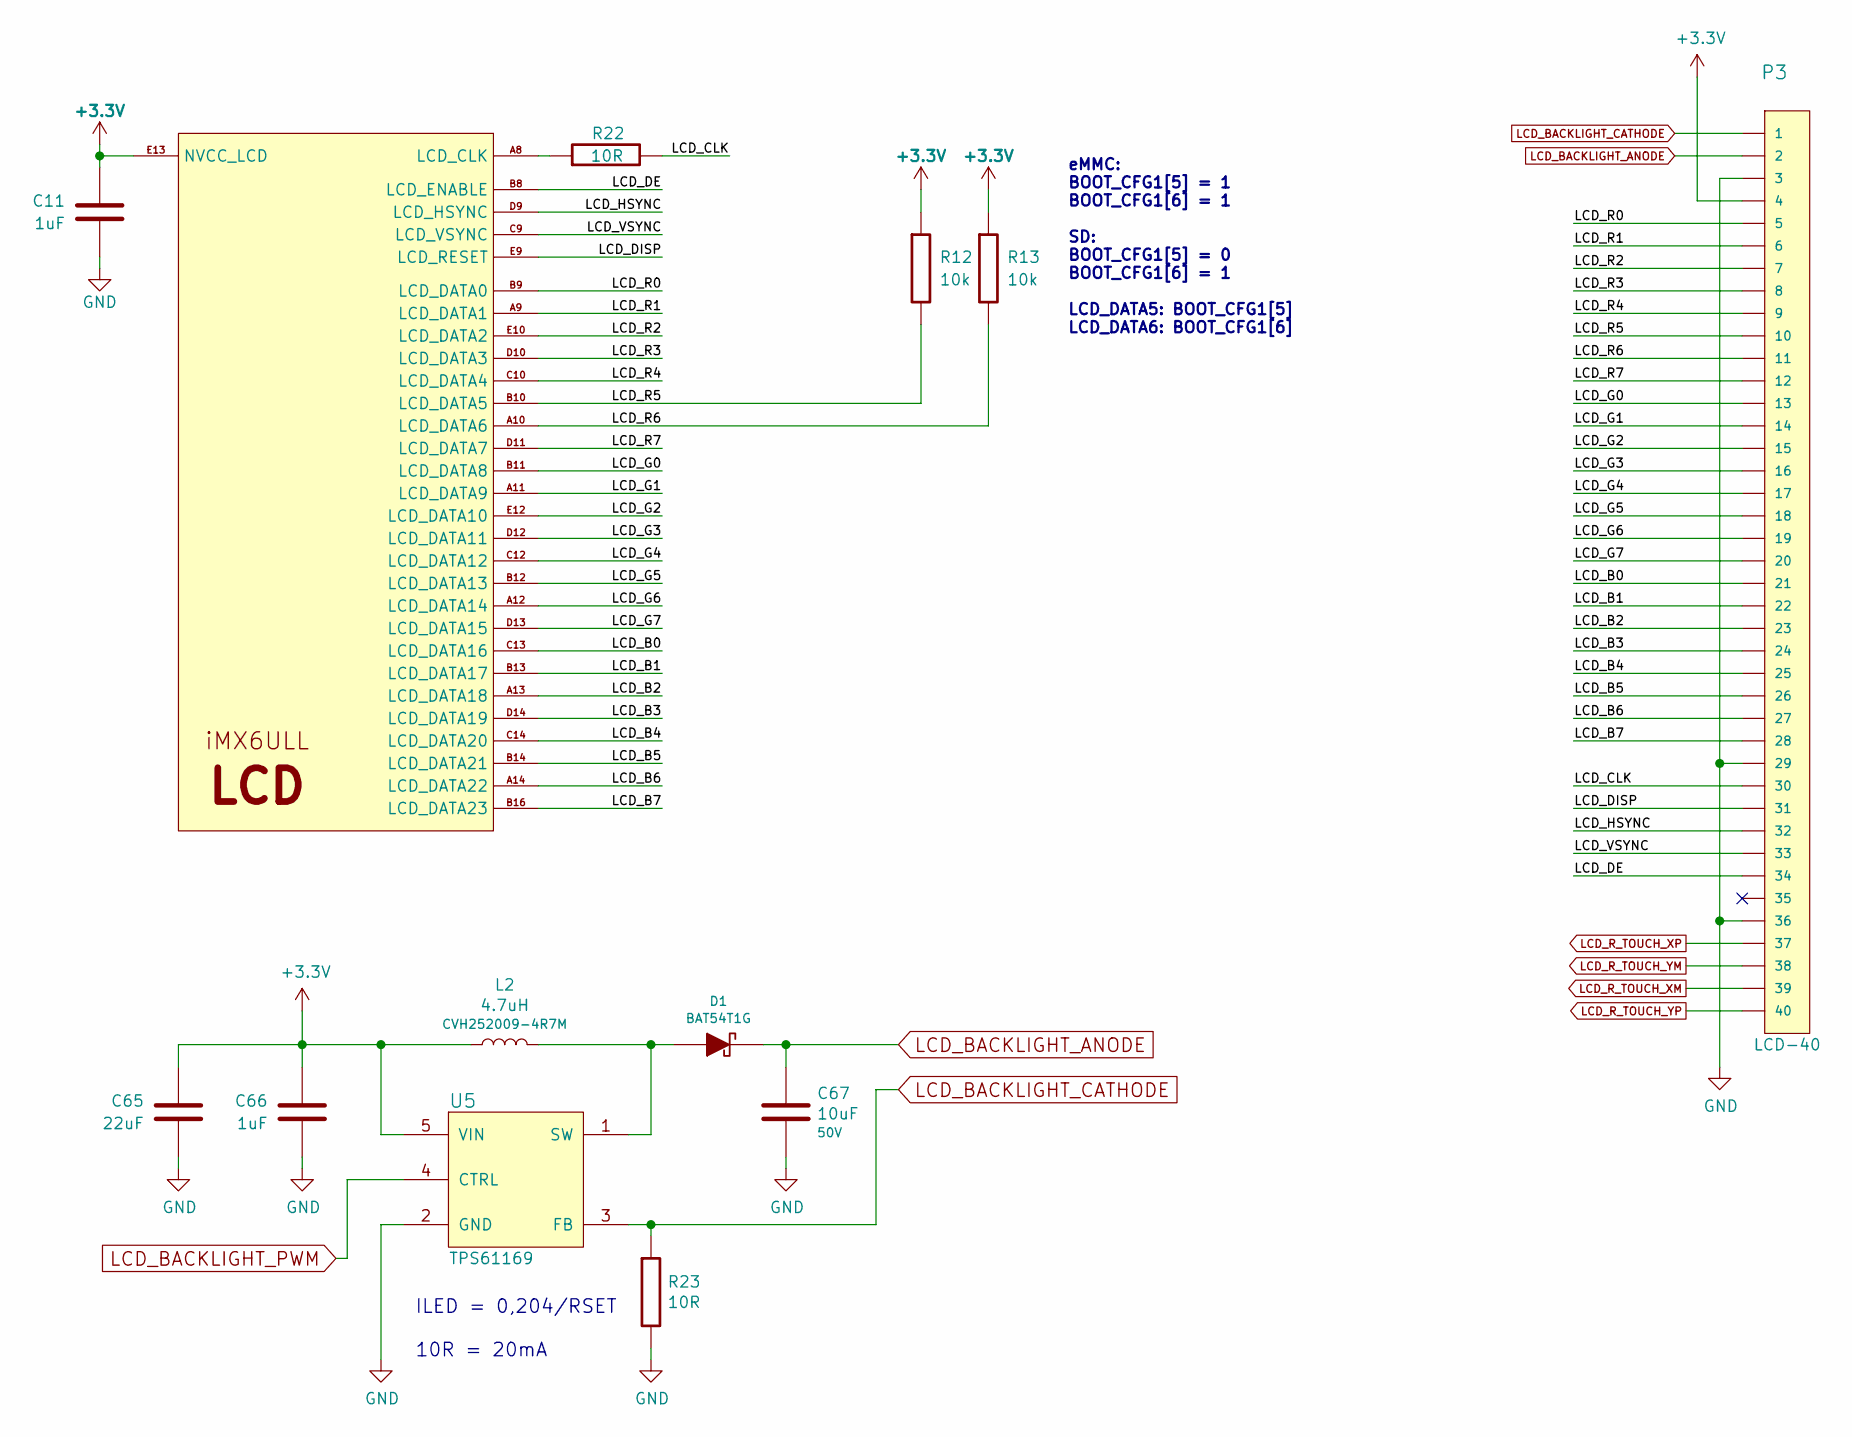
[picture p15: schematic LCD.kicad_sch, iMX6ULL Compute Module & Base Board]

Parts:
C11, C66: 1uF; IPC-SMD-C-0402; Voltage 10V
C65: 22uF; IPC-SMD-C-0603; Voltage 6.3V
C67: 10uF; IPC-SMD-C-1206; Voltage 50V
D1: BAT54T1G; IPC-SOD-123
L2: 4.7uH; IPC-SMD-R-0805; Part No CVH252009-4R7M
P3: LCD-40; Connector-SMD-ZIF-40-pin
R12, R13: 10k; IPC-SMD-R-0603
R22: 10R; IPC-SMD-R-0402
R23: 10R; IPC-SMD-R-0805
U1: iMX6ULL; BGA289C80P17X17_1400X1400X132N
U5: TPS61169; IPC-SC-70-5

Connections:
+3V3: C11.1, C65.1, C66.1, L2.2, P3.4, R12.1, R13.1, U1.E13 (NVCC_LCD), U5.5 (VIN); also elsewhere on the board
/LCD/LCD_B0: P3.21, U1.C13 (LCD_DATA16)
/LCD/LCD_B1: P3.22, U1.B13 (LCD_DATA17)
/LCD/LCD_B2: P3.23, U1.A13 (LCD_DATA18)
/LCD/LCD_B3: P3.24, U1.D14 (LCD_DATA19)
/LCD/LCD_B4: P3.25, U1.C14 (LCD_DATA20)
/LCD/LCD_B5: P3.26, U1.B14 (LCD_DATA21)
/LCD/LCD_B6: P3.27, U1.A14 (LCD_DATA22)
/LCD/LCD_B7: P3.28, U1.B16 (LCD_DATA23)
/LCD/LCD_CLK: P3.30, R22.2
/LCD/LCD_DE: P3.34, U1.B8 (LCD_ENABLE)
/LCD/LCD_DISP: P3.31, U1.E9 (LCD_RESET)
/LCD/LCD_G0: P3.13, U1.B11 (LCD_DATA8)
/LCD/LCD_G1: P3.14, U1.A11 (LCD_DATA9)
/LCD/LCD_G2: P3.15, U1.E12 (LCD_DATA10)
/LCD/LCD_G3: P3.16, U1.D12 (LCD_DATA11)
/LCD/LCD_G4: P3.17, U1.C12 (LCD_DATA12)
/LCD/LCD_G5: P3.18, U1.B12 (LCD_DATA13)
/LCD/LCD_G6: P3.19, U1.A12 (LCD_DATA14)
/LCD/LCD_G7: P3.20, U1.D13 (LCD_DATA15)
/LCD/LCD_HSYNC: P3.32, U1.D9 (LCD_HSYNC)
/LCD/LCD_R0: P3.5, U1.B9 (LCD_DATA0)
/LCD/LCD_R1: P3.6, U1.A9 (LCD_DATA1)
/LCD/LCD_R2: P3.7, U1.E10 (LCD_DATA2)
/LCD/LCD_R3: P3.8, U1.D10 (LCD_DATA3)
/LCD/LCD_R4: P3.9, U1.C10 (LCD_DATA4)
/LCD/LCD_R5: P3.10, R12.2, U1.B10 (LCD_DATA5)
/LCD/LCD_R6: P3.11, R13.2, U1.A10 (LCD_DATA6)
/LCD/LCD_R7: P3.12, U1.D11 (LCD_DATA7)
/LCD/LCD_VSYNC: P3.33, U1.C9 (LCD_VSYNC)
GND: C11.2, C65.2, C66.2, C67.2, P3.3, P3.29, P3.36, R23.2, U5.2 (GND); also elsewhere on the board
LCD_BACKLIGHT_ANODE: C67.1, D1.2 (K), P3.2
LCD_BACKLIGHT_CATHODE: P3.1, R23.1, U5.3 (FB)
LCD_BACKLIGHT_PWM: U5.4 (CTRL); also elsewhere on the board
LCD_R_TOUCH_XM: P3.39; also elsewhere on the board
LCD_R_TOUCH_XP: P3.37; also elsewhere on the board
LCD_R_TOUCH_YM: P3.38; also elsewhere on the board
LCD_R_TOUCH_YP: P3.40; also elsewhere on the board
unnamed: D1.1 (A), L2.1, U5.1 (SW)
unnamed: R22.1, U1.A8 (LCD_CLK)

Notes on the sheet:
ILED = 0,204/RSET 10R = 20mA
eMMC: BOOT_CFG1[5] = 1 BOOT_CFG1[6] = 1 SD: BOOT_CFG1[5] = 0 BOOT_CFG1[6] = 1 LCD_DATA5: BOOT_CFG1[5] LCD_DATA6: BOOT_CFG1[6]

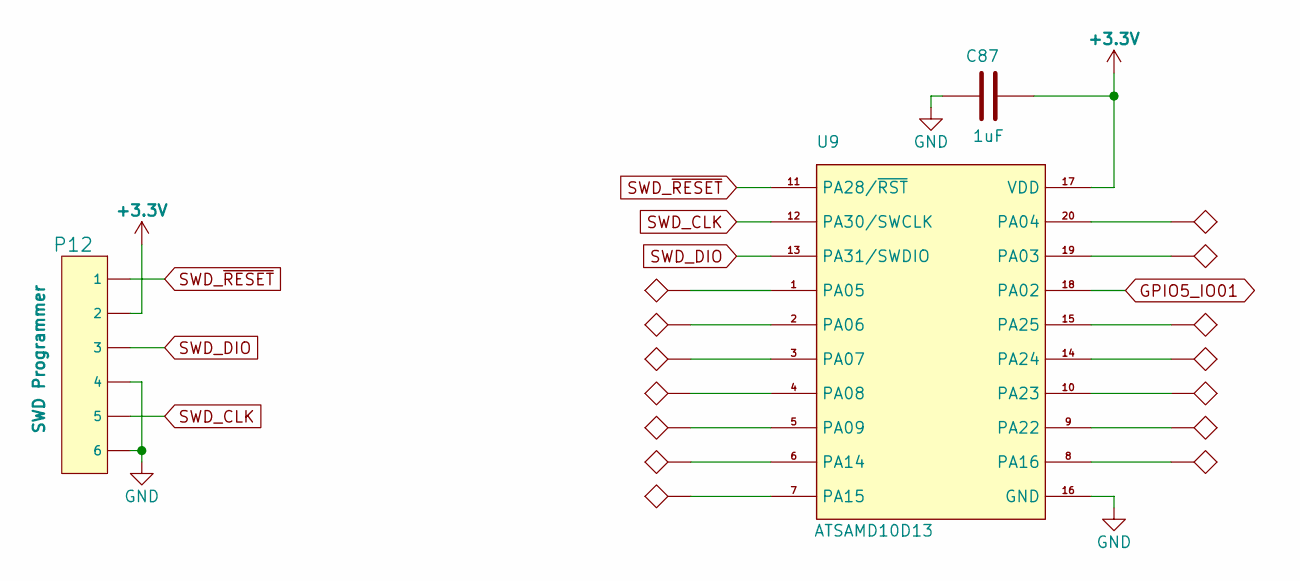
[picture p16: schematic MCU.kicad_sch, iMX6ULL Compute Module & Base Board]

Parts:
C87: 1uF; IPC-SMD-C-0402
P12: SWD Programmer; TC2030-IDC-NL-FP-6-pin
TP1, TP2, TP3, TP4, TP5, TP6, TP7, TP8, TP9, TP10, TP11, TP12, TP13, TP14: TEST_POINT; TP-40th-Without-Silkscreen
U9: ATSAMD10D13; IPC-SOIC-20

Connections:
+3V3: C87.1, P12.2, U9.17 (VDD); also elsewhere on the board
GND: C87.2, P12.4, P12.6, U9.16 (GND); also elsewhere on the board
GPIO5_IO01: U9.18 (PA02); also elsewhere on the board
unnamed: TP9.1, U9.3 (PA07)
unnamed: TP10.1, U9.10 (PA23)
unnamed: TP11.1, U9.4 (PA08)
unnamed: TP13.1, U9.1 (PA05)
unnamed: TP14.1, U9.2 (PA06)
unnamed: TP2.1, U9.5 (PA09)
unnamed: TP4.1, U9.6 (PA14)
unnamed: TP6.1, U9.7 (PA15)
unnamed: TP7.1, U9.8 (PA16)
unnamed: TP8.1, U9.9 (PA22)
unnamed: TP5.1, U9.14 (PA24)
unnamed: TP3.1, U9.15 (PA25)
unnamed: TP12.1, U9.19 (PA03)
unnamed: TP1.1, U9.20 (PA04)
SWD_CLK: P12.5, U9.12 (PA30/SWCLK)
SWD_DIO: P12.3, U9.13 (PA31/SWDIO)
SWD_~RESET: P12.1, U9.11 (PA28/~RST)

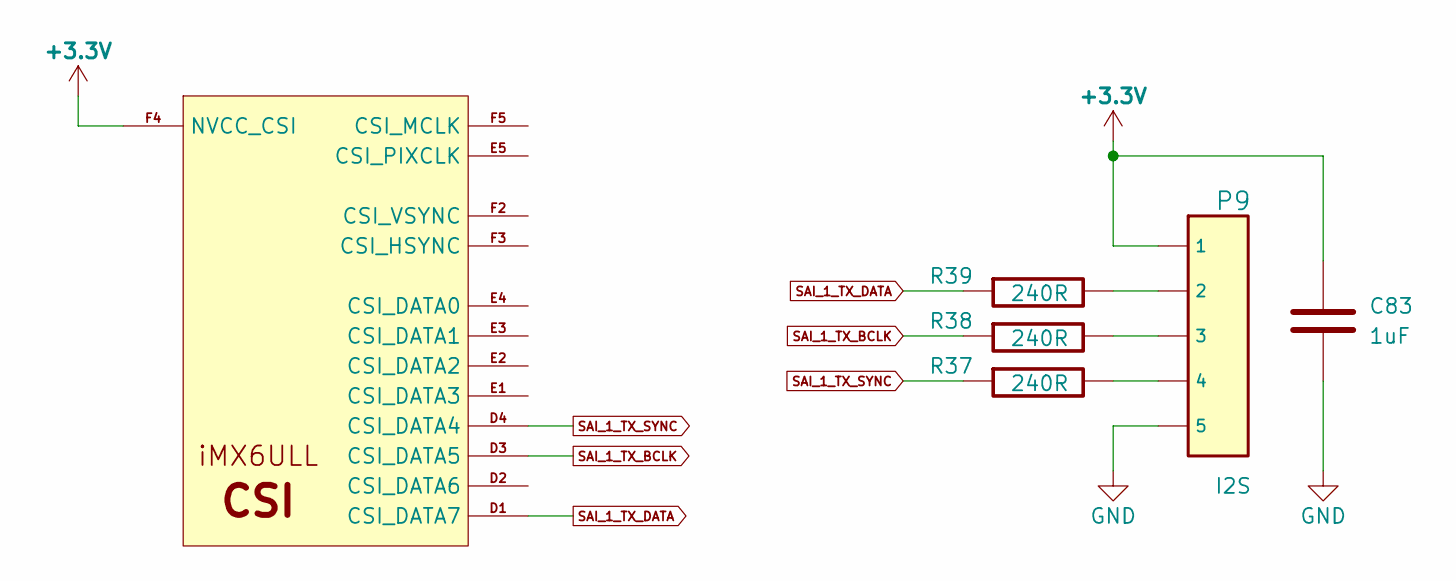
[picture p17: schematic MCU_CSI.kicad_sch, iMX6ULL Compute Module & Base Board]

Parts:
C83: 1uF; IPC-SMD-C-0402; Voltage 10V
P9: I2S; Connector-Male-Breakaway-5pins
R37, R38, R39: 240R; IPC-SMD-R-0402
U1: iMX6ULL; BGA289C80P17X17_1400X1400X132N

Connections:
+3V3: C83.1, P9.1, U1.F4 (NVCC_CSI); also elsewhere on the board
GND: C83.2, P9.5; also elsewhere on the board
unnamed: P9.2, R39.2
unnamed: P9.3, R38.2
unnamed: P9.4, R37.2
SAI_1_TX_BCLK: R38.1, U1.D3 (CSI_DATA5)
SAI_1_TX_DATA: R39.1, U1.D1 (CSI_DATA7)
SAI_1_TX_SYNC: R37.1, U1.D4 (CSI_DATA4)

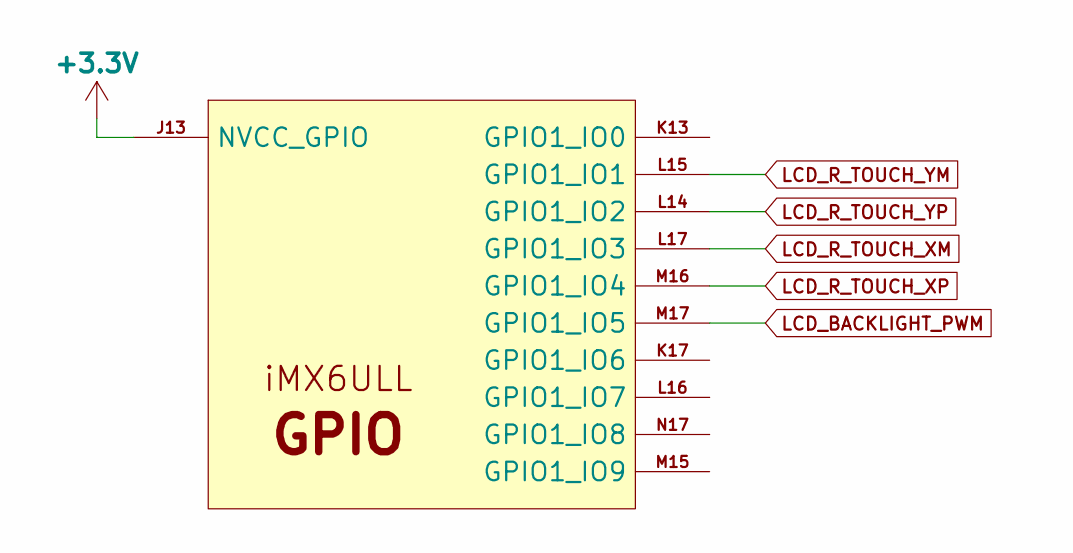
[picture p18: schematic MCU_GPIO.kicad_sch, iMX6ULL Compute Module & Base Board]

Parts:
U1: iMX6ULL; BGA289C80P17X17_1400X1400X132N

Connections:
+3V3: U1.J13 (NVCC_GPIO); also elsewhere on the board
LCD_BACKLIGHT_PWM: U1.M17 (GPIO1_IO5); also elsewhere on the board
LCD_R_TOUCH_XM: U1.L17 (GPIO1_IO3); also elsewhere on the board
LCD_R_TOUCH_XP: U1.M16 (GPIO1_IO4); also elsewhere on the board
LCD_R_TOUCH_YM: U1.L15 (GPIO1_IO1); also elsewhere on the board
LCD_R_TOUCH_YP: U1.L14 (GPIO1_IO2); also elsewhere on the board

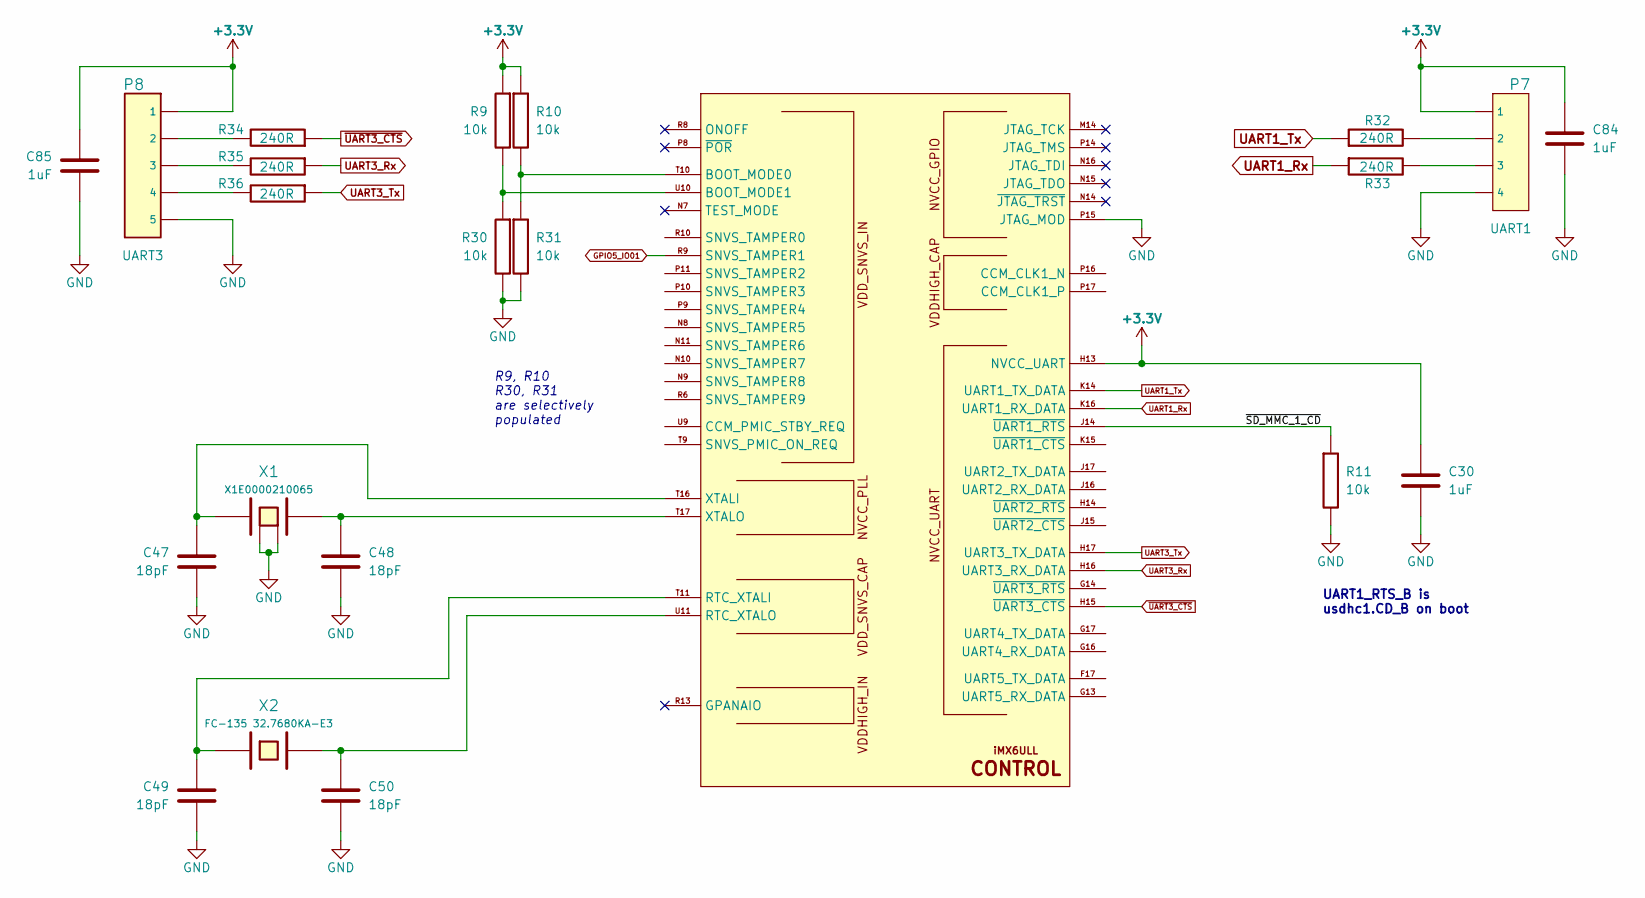
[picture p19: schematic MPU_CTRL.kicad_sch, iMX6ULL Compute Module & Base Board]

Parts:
C30, C84, C85: 1uF; IPC-SMD-C-0402; Voltage 10V
C47, C48, C49, C50: 18pF; IPC-SMD-C-0402; Voltage 50V
P7: UART1; Connector-Male-Breakaway-4pins
P8: UART3; Connector-Male-Breakaway-5pins
R9, R10, R11, R30, R31: 10k; IPC-SMD-R-0402
R32, R33, R34, R35, R36: 240R; IPC-SMD-R-0402
U1: iMX6ULL; BGA289C80P17X17_1400X1400X132N
X1: X1E0000210065; XTAL-SMD-3.2mm-2.5mm
X2: FC-135 32.7680KA-E3; CRYSTAL-EPSON-FC-135

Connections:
+3V3: C30.1, C84.1, C85.1, P7.1, P8.1, R9.1, R10.1, U1.H13 (NVCC_UART); also elsewhere on the board
/MPU_CTRL/~SD_MMC_1_CD: R11.1, U1.J14 (~UART1_RTS~)
GND: C30.2, C47.2, C48.2, C49.2, C50.2, C84.2, C85.2, P7.4, P8.5, R11.2, R30.2, R31.2, U1.P15 (JTAG_MOD), X1.2 (Case), X1.4 (Case); also elsewhere on the board
GPIO5_IO01: U1.R9 (SNVS_TAMPER1); also elsewhere on the board
unnamed: C47.1, U1.T16 (XTALI), X1.3
unnamed: C48.1, U1.T17 (XTALO), X1.1
unnamed: C49.1, U1.T11 (RTC_XTALI), X2.1
unnamed: C50.1, U1.U11 (RTC_XTALO), X2.2
unnamed: P7.2, R32.2
unnamed: P7.3, R33.2
unnamed: P8.2, R34.2
unnamed: P8.3, R35.2
unnamed: P8.4, R36.2
unnamed: R10.2, R31.1, U1.T10 (BOOT_MODE0)
unnamed: R9.2, R30.1, U1.U10 (BOOT_MODE1)
UART1_Rx: R33.1, U1.K16 (UART1_RX_DATA)
UART1_Tx: R32.1, U1.K14 (UART1_TX_DATA)
UART3_Rx: R35.1, U1.H16 (UART3_RX_DATA)
UART3_Tx: R36.1, U1.H17 (UART3_TX_DATA)
~UART3_CTS: R34.1, U1.H15 (~UART3_CTS~)

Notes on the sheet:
R9, R10 R30, R31 are selectively populated
UART1_RTS_B is usdhc1.CD_B on boot

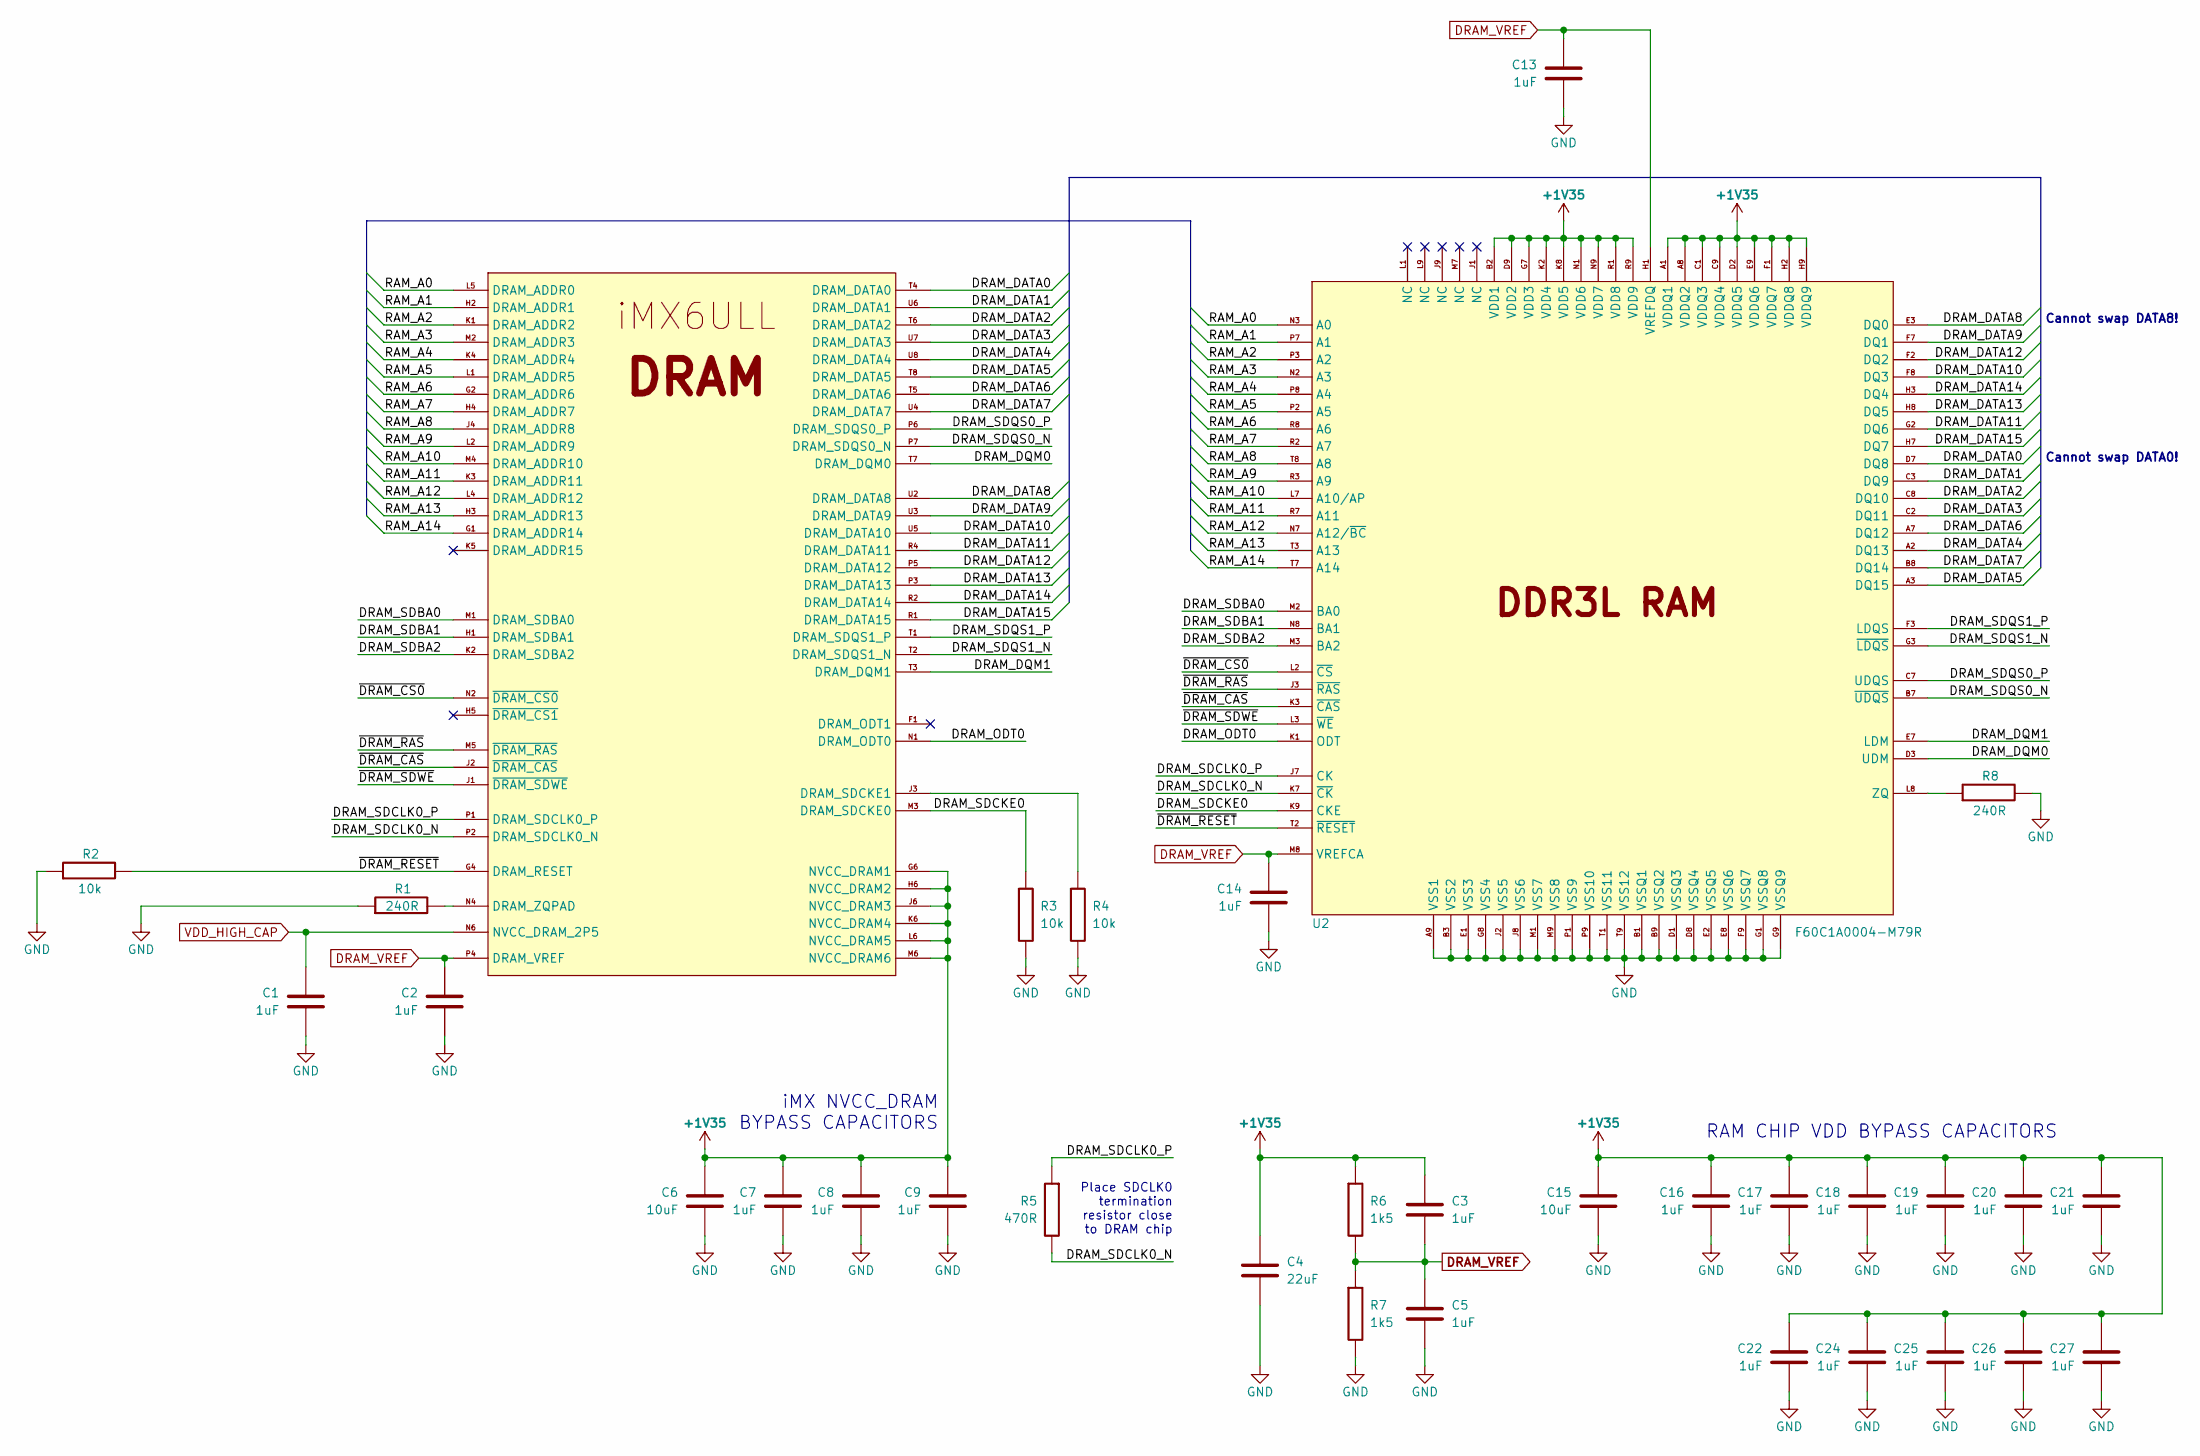
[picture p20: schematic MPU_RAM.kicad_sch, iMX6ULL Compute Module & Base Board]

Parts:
C1, C2, C7, C8, C9, C13, C14, C16, C17, C18, C19, C20, C21, C22, C24, C25, C26, C27: 1uF; IPC-SMD-C-0402; Voltage 10V
C3, C5: 1uF; IPC-SMD-C-0603; Voltage 16V
C4: 22uF; IPC-SMD-C-0603; Voltage 6.3V
C6: 10uF; IPC-SMD-C-0402; Voltage 16V
C15: 10uF; IPC-SMD-C-0805; Voltage 16V
R1, R8: 240R; IPC-SMD-R-0402
R2, R3, R4: 10k; IPC-SMD-R-0402
R5: 470R; IPC-SMD-R-0402
R6, R7: 1k5; IPC-SMD-R-0603
U1: iMX6ULL; BGA289C80P17X17_1400X1400X132N
U2: F60C1A0004-M79R; BGA96C80P9X16_1400X800X120

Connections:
+1V35: C3.1, C4.1, C6.1, C7.1, C8.1, C9.1, C15.1, C16.1, C17.1, C18.1, C19.1, C20.1, C21.1, C22.1, C24.1, C25.1, C26.1, C27.1, R6.1, U1.G6 (NVCC_DRAM1), U1.H6 (NVCC_DRAM2), U1.J6 (NVCC_DRAM3), U1.K6 (NVCC_DRAM4), U1.L6 (NVCC_DRAM5), U1.M6 (NVCC_DRAM6), U2.A1 (VDDQ1), U2.A8 (VDDQ2), U2.B2 (VDD1), U2.C1 (VDDQ3), U2.C9 (VDDQ4), U2.D2 (VDDQ5), U2.D9 (VDD2), U2.E9 (VDDQ6), U2.F1 (VDDQ7), U2.G7 (VDD3), U2.H2 (VDDQ8), U2.H9 (VDDQ9), U2.K2 (VDD4), U2.K8 (VDD5), U2.N1 (VDD6), U2.N9 (VDD7), U2.R1 (VDD8), U2.R9 (VDD9); also elsewhere on the board
/MPU_DRAM/DRAM_DATA0: U1.T4 (DRAM_DATA0), U2.D7 (DQ8)
/MPU_DRAM/DRAM_DATA1: U1.U6 (DRAM_DATA1), U2.C3 (DQ9)
/MPU_DRAM/DRAM_DATA2: U1.T6 (DRAM_DATA2), U2.C8 (DQ10)
/MPU_DRAM/DRAM_DATA3: U1.U7 (DRAM_DATA3), U2.C2 (DQ11)
/MPU_DRAM/DRAM_DATA4: U1.U8 (DRAM_DATA4), U2.A2 (DQ13)
/MPU_DRAM/DRAM_DATA5: U1.T8 (DRAM_DATA5), U2.A3 (DQ15)
/MPU_DRAM/DRAM_DATA6: U1.T5 (DRAM_DATA6), U2.A7 (DQ12)
/MPU_DRAM/DRAM_DATA7: U1.U4 (DRAM_DATA7), U2.B8 (DQ14)
/MPU_DRAM/DRAM_DATA8: U1.U2 (DRAM_DATA8), U2.E3 (DQ0)
/MPU_DRAM/DRAM_DATA9: U1.U3 (DRAM_DATA9), U2.F7 (DQ1)
/MPU_DRAM/DRAM_DATA10: U1.U5 (DRAM_DATA10), U2.F8 (DQ3)
/MPU_DRAM/DRAM_DATA11: U1.R4 (DRAM_DATA11), U2.G2 (DQ6)
/MPU_DRAM/DRAM_DATA12: U1.P5 (DRAM_DATA12), U2.F2 (DQ2)
/MPU_DRAM/DRAM_DATA13: U1.P3 (DRAM_DATA13), U2.H8 (DQ5)
/MPU_DRAM/DRAM_DATA14: U1.R2 (DRAM_DATA14), U2.H3 (DQ4)
/MPU_DRAM/DRAM_DATA15: U1.R1 (DRAM_DATA15), U2.H7 (DQ7)
/MPU_DRAM/DRAM_DQM0: U1.T7 (DRAM_DQM0), U2.D3 (UDM)
/MPU_DRAM/DRAM_DQM1: U1.T3 (DRAM_DQM1), U2.E7 (LDM)
/MPU_DRAM/DRAM_ODT0: U1.N1 (DRAM_ODT0), U2.K1 (ODT)
/MPU_DRAM/DRAM_SDBA0: U1.M1 (DRAM_SDBA0), U2.M2 (BA0)
/MPU_DRAM/DRAM_SDBA1: U1.H1 (DRAM_SDBA1), U2.N8 (BA1)
/MPU_DRAM/DRAM_SDBA2: U1.K2 (DRAM_SDBA2), U2.M3 (BA2)
/MPU_DRAM/DRAM_SDCKE0: R3.1, U1.M3 (DRAM_SDCKE0), U2.K9 (CKE)
/MPU_DRAM/DRAM_SDCLK0_N: R5.2, U1.P2 (DRAM_SDCLK0_N), U2.K7 (~CK~)
/MPU_DRAM/DRAM_SDCLK0_P: R5.1, U1.P1 (DRAM_SDCLK0_P), U2.J7 (CK)
/MPU_DRAM/DRAM_SDQS0_N: U1.P7 (DRAM_SDQS0_N), U2.B7 (~UDQS~)
/MPU_DRAM/DRAM_SDQS0_P: U1.P6 (DRAM_SDQS0_P), U2.C7 (UDQS)
/MPU_DRAM/DRAM_SDQS1_N: U1.T2 (DRAM_SDQS1_N), U2.G3 (~LDQS~)
/MPU_DRAM/DRAM_SDQS1_P: U1.T1 (DRAM_SDQS1_P), U2.F3 (LDQS)
/MPU_DRAM/RAM_A0: U1.L5 (DRAM_ADDR0), U2.N3 (A0)
/MPU_DRAM/RAM_A1: U1.H2 (DRAM_ADDR1), U2.P7 (A1)
/MPU_DRAM/RAM_A2: U1.K1 (DRAM_ADDR2), U2.P3 (A2)
/MPU_DRAM/RAM_A3: U1.M2 (DRAM_ADDR3), U2.N2 (A3)
/MPU_DRAM/RAM_A4: U1.K4 (DRAM_ADDR4), U2.P8 (A4)
/MPU_DRAM/RAM_A5: U1.L1 (DRAM_ADDR5), U2.P2 (A5)
/MPU_DRAM/RAM_A6: U1.G2 (DRAM_ADDR6), U2.R8 (A6)
/MPU_DRAM/RAM_A7: U1.H4 (DRAM_ADDR7), U2.R2 (A7)
/MPU_DRAM/RAM_A8: U1.J4 (DRAM_ADDR8), U2.T8 (A8)
/MPU_DRAM/RAM_A9: U1.L2 (DRAM_ADDR9), U2.R3 (A9)
/MPU_DRAM/RAM_A10: U1.M4 (DRAM_ADDR10), U2.L7 (A10/AP)
/MPU_DRAM/RAM_A11: U1.K3 (DRAM_ADDR11), U2.R7 (A11)
/MPU_DRAM/RAM_A12: U1.L4 (DRAM_ADDR12), U2.N7 (A12/~BC~)
/MPU_DRAM/RAM_A13: U1.H3 (DRAM_ADDR13), U2.T3 (A13)
/MPU_DRAM/RAM_A14: U1.G1 (DRAM_ADDR14), U2.T7 (A14)
/MPU_DRAM/~DRAM_CAS: U1.J2 (~DRAM_CAS~), U2.K3 (~CAS~)
/MPU_DRAM/~DRAM_CS0: U1.N2 (~DRAM_CS0~), U2.L2 (~CS~)
/MPU_DRAM/~DRAM_RAS: U1.M5 (~DRAM_RAS~), U2.J3 (~RAS~)
/MPU_DRAM/~DRAM_RESET: R2.2, U1.G4 (DRAM_RESET), U2.T2 (~RESET~)
/MPU_DRAM/~DRAM_SDWE: U1.J1 (~DRAM_SDWE~), U2.L3 (~WE~)
DRAM_VREF: C2.1, C3.2, C5.1, C13.1, C14.1, R6.2, R7.1, U1.P4 (DRAM_VREF), U2.H1 (VREFDQ), U2.M8 (VREFCA)
GND: C1.2, C2.2, C4.2, C5.2, C6.2, C7.2, C8.2, C9.2, C13.2, C14.2, C15.2, C16.2, C17.2, C18.2, C19.2, C20.2, C21.2, C22.2, C24.2, C25.2, C26.2, C27.2, R1.1, R2.1, R3.2, R4.2, R7.2, R8.2, U2.A9 (VSS1), U2.B1 (VSSQ1), U2.B3 (VSS2), U2.B9 (VSSQ2), U2.D1 (VSSQ3), U2.D8 (VSSQ4), U2.E1 (VSS3), U2.E2 (VSSQ5), U2.E8 (VSSQ6), U2.F9 (VSSQ7), U2.G1 (VSSQ8), U2.G8 (VSS4), U2.G9 (VSSQ9), U2.J2 (VSS5), U2.J8 (VSS6), U2.M1 (VSS7), U2.M9 (VSS8), U2.P1 (VSS9), U2.P9 (VSS10), U2.T1 (VSS11), U2.T9 (VSS12); also elsewhere on the board
unnamed: R1.2, U1.N4 (DRAM_ZQPAD)
unnamed: R4.1, U1.J3 (DRAM_SDCKE1)
unnamed: R8.1, U2.L8 (ZQ)
VDD_HIGH_CAP: C1.1, U1.N6 (NVCC_DRAM_2P5); also elsewhere on the board

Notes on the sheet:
iMX NVCC_DRAM BYPASS CAPACITORS
Place SDCLK0 termination resistor close to DRAM chip
RAM CHIP VDD BYPASS CAPACITORS
Cannot swap DATA8!
Cannot swap DATA0!

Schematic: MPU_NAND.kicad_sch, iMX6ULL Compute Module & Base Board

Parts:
C10, C86: 1uF; IPC-SMD-C-0402; Voltage 10V
D3: LED; IPC-SMD-LED-0805
P10: ECSPI4; Connector-Male-Breakaway-7pins
R40, R41, R42, R43, R44: 240R; IPC-SMD-R-0402
R47: 1k5; IPC-SMD-R-0603
U1: iMX6ULL; BGA289C80P17X17_1400X1400X132N

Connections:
ECSPI4_MISO: R43.2, U1.A6 (NAND_DATA6)
ECSPI4_MOSI: R41.2, U1.B6 (NAND_DATA5)
ECSPI4_SCLK: R40.2, U1.C6 (NAND_DATA4)
ECSPI4_SS0: R42.2, U1.A5 (NAND_DATA7)
ECSPI4_SS1: R44.2, U1.B7 (NAND_DATA1)
+3V3: C10.1, C86.1, P10.1, U1.E7 (NVCC_NAND); also elsewhere on the board
GND: C10.2, C86.2, D3.2 (K), P10.7; also elsewhere on the board
unnamed: D3.1 (A), R47.2
unnamed: P10.2, R40.1
unnamed: P10.3, R41.1
unnamed: P10.4, R42.1
unnamed: P10.5, R43.1
unnamed: P10.6, R44.1
unnamed: R47.1, U1.A7 (NAND_DATA2)
SD1_DATA4: U1.A3 (~NAND_READY~)
SD1_DATA5: U1.C5 (~NAND_CE0~)
SD1_DATA6: U1.B5 (~NAND_CE1~)
SD1_DATA7: U1.A4 (NAND_CLE)

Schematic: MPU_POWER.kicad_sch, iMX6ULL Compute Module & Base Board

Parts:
C29, C31, C32, C33, C34, C36, C37, C38, C42, C43, C45: 1uF; IPC-SMD-C-0402; Voltage 10V
C35, C39, C40: 22uF; IPC-SMD-C-0603; Voltage 6.3V
C41, C44, C46: 10uF; IPC-SMD-C-0402; Voltage 16V
U1: iMX6ULL; BGA289C80P17X17_1400X1400X132N

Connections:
+1V35: C29.1, C40.1, U1.H9 (VDD_SOC_IN1), U1.H10 (VDD_SOC_IN2), U1.J9 (VDD_SOC_IN3), U1.J10 (VDD_SOC_IN4), U1.K9 (VDD_SOC_IN5), U1.K10 (VDD_SOC_IN6); also elsewhere on the board
+3V3: C31.1, C32.1, C41.1, U1.L13 (VDDA_ADC_3P3), U1.M13 (ADC_VREFH), U1.N13 (VDD_HIGH_IN), U1.P12 (VDD_SNVS_IN); also elsewhere on the board
/MPU_POWER/NVCC_PLL: C43.1, C44.1, U1.P13 (NVCC_PLL)
/MPU_POWER/VDD_ARM_CAP: C33.1, C34.1, C35.1, U1.G9 (VDD_ARM_CAP_1), U1.G10 (VDD_ARM_CAP_2), U1.G11 (VDD_ARM_CAP_3), U1.H11 (VDD_ARM_CAP_4)
/MPU_POWER/VDD_SNVS_CAP: C42.1, U1.N12 (VDD_SNVS_CAP)
/MPU_POWER/VDD_SOC_CAP: C36.1, C37.1, C38.1, C39.1, U1.G8 (VDD_SOC_CAP1), U1.H8 (VDD_SOC_CAP2), U1.J8 (VDD_SOC_CAP3), U1.J11 (VDD_SOC_CAP4), U1.K8 (VDD_SOC_CAP5), U1.K11 (VDD_SOC_CAP6), U1.L8 (VDD_SOC_CAP7), U1.L9 (VDD_SOC_CAP8), U1.L10 (VDD_SOC_CAP9), U1.L11 (VDD_SOC_CAP10)
GND: C29.2, C31.2, C32.2, C33.2, C34.2, C35.2, C36.2, C37.2, C38.2, C39.2, C40.2, C41.2, C42.2, C43.2, C44.2, C45.2, C46.2, U1.A1 (VSS1), U1.A17 (VSS2), U1.C3 (VSS3), U1.C7 (VSS4), U1.C11 (VSS5), U1.C15 (VSS6), U1.E8 (VSS7), U1.E11 (VSS8), U1.F6 (VSS9), U1.F7 (VSS10), U1.F8 (VSS11), U1.F9 (VSS12), U1.F10 (VSS13), U1.F11 (VSS14), U1.F12 (VSS15), U1.G3 (VSS16), U1.G5 (VSS17), U1.G7 (VSS18), U1.G12 (VSS19), U1.G15 (VSS20), U1.H7 (VSS21), U1.H12 (VSS22), U1.J5 (VSS23), U1.J7 (VSS24), U1.J12 (VSS25), U1.K7 (VSS26), U1.K12 (VSS27), U1.L3 (VSS28), U1.L7 (VSS29), U1.L12 (VSS30), U1.M7 (VSS31), U1.M8 (VSS32), U1.M9 (VSS33), U1.M10 (VSS34), U1.M11 (VSS35), U1.M12 (NGND_KEL0), U1.N3 (VSS36), U1.N5 (VSS37), U1.R3 (VSS38), U1.R5 (VSS39), U1.R7 (VSS40), U1.R11 (VSS41), U1.R16 (VSS42), U1.R17 (VSS43), U1.T14 (VSS44), U1.U1 (VSS45), U1.U14 (VSS46), U1.U17 (VSS47); also elsewhere on the board
VDD_HIGH_CAP: C45.1, C46.1, U1.R14 (VDD_HIGH_CAP1), U1.R15 (VDD_HIGH_CAP2); also elsewhere on the board

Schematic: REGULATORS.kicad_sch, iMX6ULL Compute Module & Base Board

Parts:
C71, C74, C76, C78, C80: 10uF; IPC-SMD-C-0805; Voltage 16V
C72, C77, C81: 220uF; ELKO-DIA-6.5mm-PS-2.54mm; Voltage 16V
C73: 100nF; IPC-SMD-C-0805; Voltage 50V
C75, C79: 100nF; IPC-SMD-C-0805; Voltage V
C82: 1uF; IPC-SMD-C-0402; Voltage 10V
D2: ES1D; IPC-DO-214AC(SMA)
L1, L3: 10uH; Inductor-SMD-FPI0403S-100M
P6: POWER IN; Connector-DG127-5.08-02P
R25, R27, R28: 10k; IPC-SMD-R-0402
R26: 33k2; IPC-SMD-R-0402
R29: 7k68; IPC-SMD-R-0402
U6: 78L05; TO92
U7, U8: TPS56x200; IPC-SOT-23-6

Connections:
+1V35: C80.1, C81.1, L3.1, R29.2; also elsewhere on the board
+3V3: C76.1, C77.1, L1.1, R26.2, R27.1; also elsewhere on the board
+5V: C74.1, U6.1 (VO); also elsewhere on the board
+12V: C71.1, C72.1, C73.1, C78.1, D2.2 (K), P6.1, U6.3 (VI), U7.3 (VIN), U7.5 (EN), U8.3 (VIN)
GND: C71.2, C72.2, C73.2, C74.2, C76.2, C77.2, C78.2, C80.2, C81.2, C82.2, D2.1 (A), P6.2, R25.1, R28.1, U6.2 (GND), U7.1 (GND), U8.1 (GND); also elsewhere on the board
unnamed: C75.1, U7.6 (VBST)
unnamed: C75.2, L1.2, U7.2 (SW)
unnamed: C79.1, U8.6 (VBST)
unnamed: C79.2, L3.2, U8.2 (SW)
unnamed: C82.1, R27.2, U8.5 (EN)
unnamed: R25.2, R26.1, U7.4 (VFB)
unnamed: R28.2, R29.1, U8.4 (VFB)

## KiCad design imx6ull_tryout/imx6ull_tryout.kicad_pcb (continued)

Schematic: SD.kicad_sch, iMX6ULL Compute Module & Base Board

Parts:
C12, C23, C53, C54, C56, C57, C58: 1uF; IPC-SMD-C-0402; Voltage 10V
C51, C52, C55: 22uF; IPC-SMD-C-0603; Voltage 6.3V
P1: 47352-1001; Connector-uSD-Molex-47352-1001
R14, R15: 10k; IPC-SMD-R-0402
U1: iMX6ULL; BGA289C80P17X17_1400X1400X132N
U3: FEMDRM008G-58A39; 153-VFBGA

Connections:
+3V3: C12.1, C23.1, C51.1, C52.1, C53.1, C54.1, P1.4 (Vdd), R14.1, R15.1, U1.C4 (NVCC_SD1), U3.E6 (VCC), U3.F5 (VCC), U3.J10 (VCC), U3.K9 (VCC); also elsewhere on the board
/SD/eMMC/SD1_CLK: P1.5 (CLK), U1.C1 (SD1_CLK), U3.M6 (CLK)
/SD/eMMC/SD1_CMD: P1.3 (CMD), R15.2, U1.C2 (SD1_CMD), U3.M5 (CMD)
/SD/eMMC/SD1_DATA0: P1.7 (DAT0), R14.2, U1.B3 (SD1_DATA0), U3.A3 (DAT0)
/SD/eMMC/SD1_DATA1: P1.8 (DAT1), U1.B2 (SD1_DATA1), U3.A4 (DAT1)
/SD/eMMC/SD1_DATA2: P1.1 (DAT2), U1.B1 (SD1_DATA2), U3.A5 (DAT2)
/SD/eMMC/SD1_DATA3: P1.2 (DAT3/CD), U1.A2 (SD1_DATA3), U3.B2 (DAT3)
GND: C12.2, C23.2, C51.2, C52.2, C53.2, C54.2, C55.2, C56.2, C57.2, C58.2, P1.6 (Vss), P1.10 (Shield), U3.A6 (VSS), U3.C4 (VSSQ), U3.E7 (VSS), U3.G5 (VSS), U3.H10 (VSS), U3.J5 (VSS), U3.K8 (VSS), U3.N2 (VSSQ), U3.N5 (VSSQ), U3.P4 (VSSQ), U3.P6 (VSSQ); also elsewhere on the board
unnamed: C55.1, C56.1, C57.1, U3.C6 (VCCQ), U3.M4 (VCCQ), U3.N4 (VCCQ), U3.P3 (VCCQ), U3.P5 (VCCQ)
unnamed: C58.1, U3.C2 (VDDI)

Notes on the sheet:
DAT0 and CMD are open drain at the time of initialization
eMMC Option
DNP, No Footprints For future reference only
uSD Option

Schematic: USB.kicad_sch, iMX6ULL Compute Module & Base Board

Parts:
C28, C68: 1uF; IPC-SMD-C-0402; Voltage 10V
C69: 22uF; IPC-SMD-C-0603; Voltage 6.3V
P4, P5: DS1095-WNR0; Connector-USB-A-Female-DS1095-WNR0
U1: iMX6ULL; BGA289C80P17X17_1400X1400X132N

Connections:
+5V: C28.1, P4.1, P5.1, U1.T12 (USB_OTG1_VBUS), U1.U12 (USB_OTG2_VBUS); also elsewhere on the board
/USB/USB1_D_N: P4.2, U1.T15 (USB_OTG1_DN)
/USB/USB1_D_P: P4.3, U1.U15 (USB_OTG1_DP)
/USB/USB2_D_N: P5.2, U1.T13 (USB_OTG2_DN)
/USB/USB2_D_P: P5.3, U1.U13 (USB_OTG2_DP)
GND: C28.2, C68.2, C69.2, P4.5, P5.5; also elsewhere on the board
unnamed: C68.1, C69.1, U1.R12 (VDD_USB_CAP)

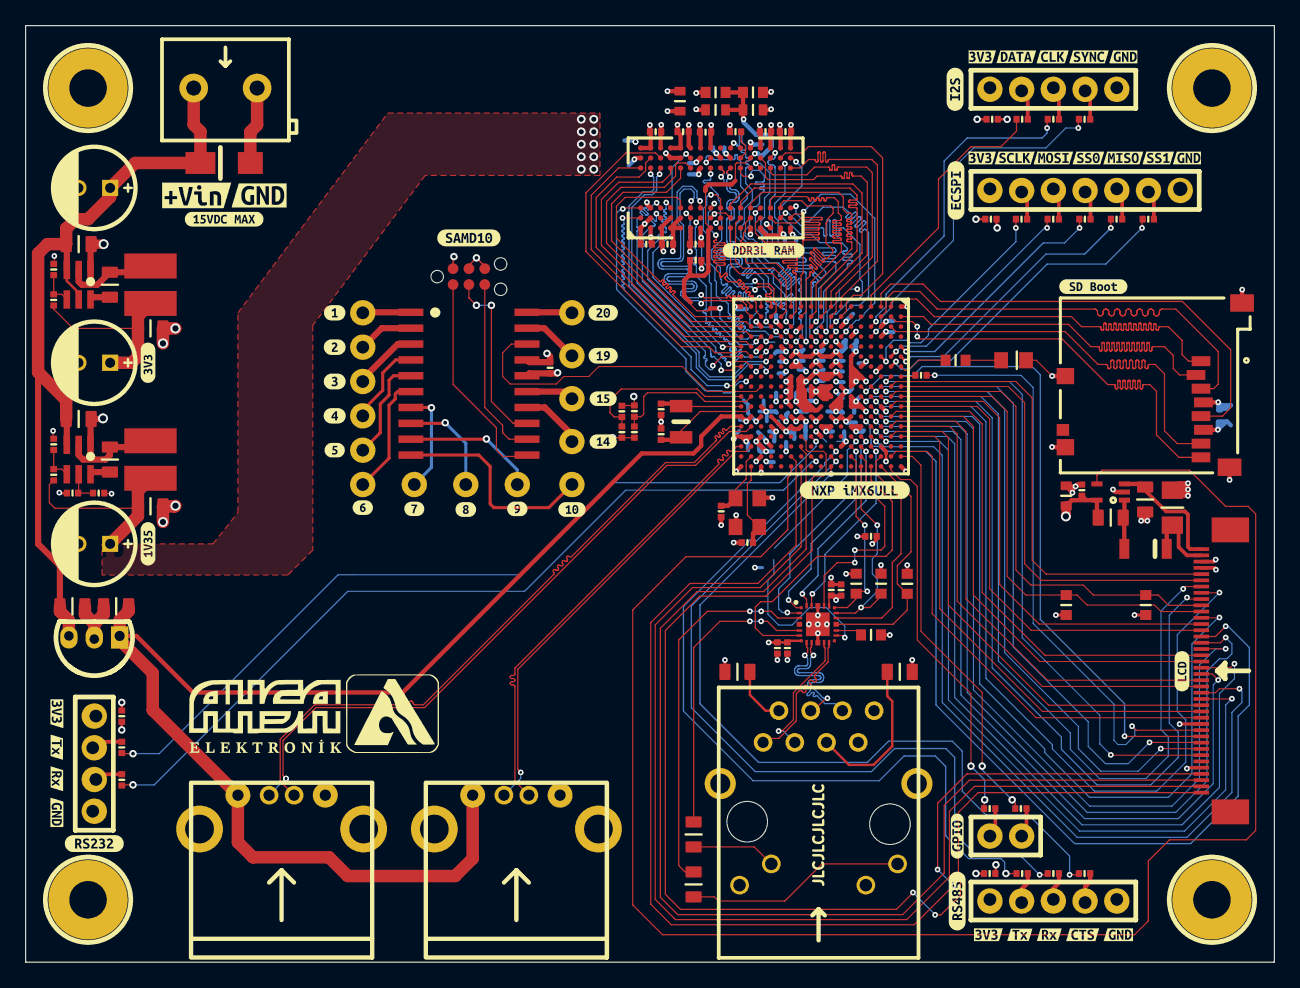
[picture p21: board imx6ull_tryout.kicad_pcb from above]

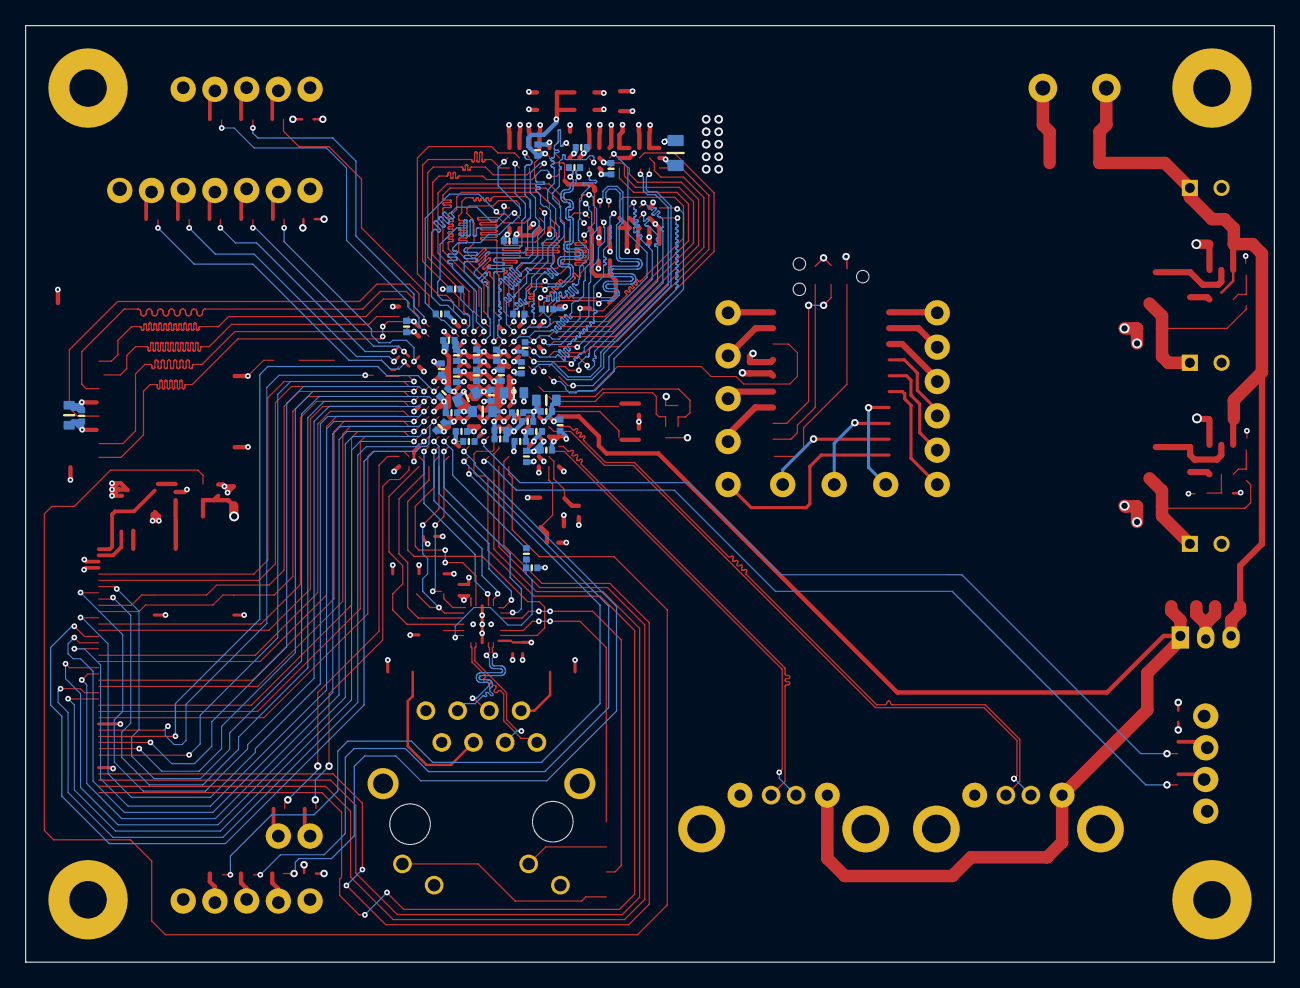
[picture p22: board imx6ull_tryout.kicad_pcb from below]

Board: 4 copper layers, 100.0 x 75.0 mm, 222 parts (45 on the bottom side), 199 nets.

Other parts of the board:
C60#2: 1uF; IPC-SMD-C-0402
svg2mod, svg2mod#2, svg2mod#3, svg2mod#4, svg2mod#5, svg2mod#6, svg2mod#7, svg2mod#8, svg2mod#9, svg2mod#10, svg2mod#11, svg2mod#12, svg2mod#13, svg2mod#14, svg2mod#15, svg2mod#16, svg2mod#17, svg2mod#18, svg2mod#19, svg2mod#20, svg2mod#21, svg2mod#22, svg2mod#23, svg2mod#24, svg2mod#25, svg2mod#26, svg2mod#27, svg2mod#28, svg2mod#29, svg2mod#30, svg2mod#31, svg2mod#32, svg2mod#33, svg2mod#34, svg2mod#35, svg2mod#36, svg2mod#37, svg2mod#38, svg2mod#39, svg2mod#40, svg2mod#41, svg2mod#42, svg2mod#43, svg2mod#44, svg2mod#45, svg2mod#46, svg2mod#47, svg2mod#48, svg2mod#49, svg2mod#50: G***; svg2mod

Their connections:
+3V3: C60#2.1; also elsewhere on the board
GND: C60#2.2; also elsewhere on the board
